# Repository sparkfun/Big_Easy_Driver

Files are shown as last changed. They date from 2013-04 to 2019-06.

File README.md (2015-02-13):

SparkFun Big Easy Driver
========================

SparkFun Big Easy Driver

[*SparkFun Big Easy Driver (ROB-12859)*](https://www.sparkfun.com/products/12859)

This is a stepper motor driver board capable of driving bi-polar stepper motors at up to 2A/phase.

Repository Contents
-------------------

* **/Firmware** - Example Arduino sketches 
* **/Hardware** - All Eagle design files (.brd, .sch)
* **/Production** - Test bed files and production panel files

Product Versions
----------------
* [ROB-12859](https://www.sparkfun.com/products/12859)- Version 1.6. Currently available. 
* [ROB-11876](https://www.sparkfun.com/products/retired/11876)- Version 1.5. Retired. 
* [ROB-11699](https://www.sparkfun.com/products/retired/11699)- Version 1.3. Retired. 
* [ROB-10735](https://www.sparkfun.com/products/retired/10735)- Version 1.2. Retired.

Version History
---------------
* [Hw-v1.6_Fw-v1.0](https://github.com/sparkfun/Big_Easy_Driver/tree/HW-v1.6_Fw-v1.0) -GitHub tag for hardware version 1.6, firmware version 1.0.  
* [HW-v1.5](https://github.com/sparkfun/Big_Easy_Driver/tree/HW-v1.5) - GitHub tag for Hardware version 1.5. 

License Information
-------------------
The hardware is released under [Creative Commons Share-alike 3.0](http://creativecommons.org/licenses/by-sa/3.0/).  

The code is beerware; if you see me (or any other SparkFun employee) at the local, and you've found our code helpful, please buy us a round!

Distributed as-is; no warranty is given.

Getting Started Help
--------------------
There's a great [Big Easy Driver Hookup Guide](https://learn.sparkfun.com/tutorials/big-easy-driver-hookup-guide) by SparkFun.

There are six example sketches in the **/Firmware** directory. Examples 1 through 5 have hookup diagrams and explanations on the [Easy Driver Examples](http://www.schmalzhaus.com/EasyDriver/Examples/EasyDriverExamples.html) page.

_This is a collaboration with Brian Schmalz._

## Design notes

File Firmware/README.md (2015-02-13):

SparkFun Big Easy Driver Example Code
======================================

Repository Contents
-------------------
* **/Arduija_Demo** - Firmware for the [Arduija Project](https://www.sparkfun.com/news/1631). 
* **/SparkFun_Big_Easy_Driver_Basic_Demo** - Firmware for the [Big Easy Driver Hookup Guide](https://learn.sparkfun.com/tutorials/big-easy-driver-hookup-guide).

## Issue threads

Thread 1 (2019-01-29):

Error on Code?

caroline-kornbrek, 2019-01-29:
I have been having trouble with the phrase  'resetBEDPins' . Whenever I try to verify my code, I get the message 'resetBEDPins' referring to the occurrence of this phrase in the void setup and void loop functions. As a result, I have been unable to get the code uploaded.

caroline-kornbrek, 2019-01-29:
I think we may be having the same conversation on github as well. I posted the question twice because I was not expecting a response so quickly. Where would you like to discuss? Thank you so much for your help.

Thanks,
Caroline Kornbrek

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

EmbeddedMan, 2019-01-29:
Caroline - when you post to GitHub, it comes through email as well. You can reply to either - they all show up on GH.

When I copy/pasted the code you provided into Arduino 1.8.7 and built for Arduino uno, I didn't get any errors or warnings.

Can you copy/paste the output of your compile (make sure to turn on verbose output for compilation in the preferences dialog box for Arduino first)? Maybe there's a clue there.

caroline-kornbrek, 2019-01-29:
Checking that box in the preferences allowed it to verify. Thank you!

EmbeddedMan, 2019-01-29:
Very good. I'm going to close this issue since the original issue appears to be solved. Please let us know if you have any other problems with the Big Easy Driver board.

Closed 2019-01-29.

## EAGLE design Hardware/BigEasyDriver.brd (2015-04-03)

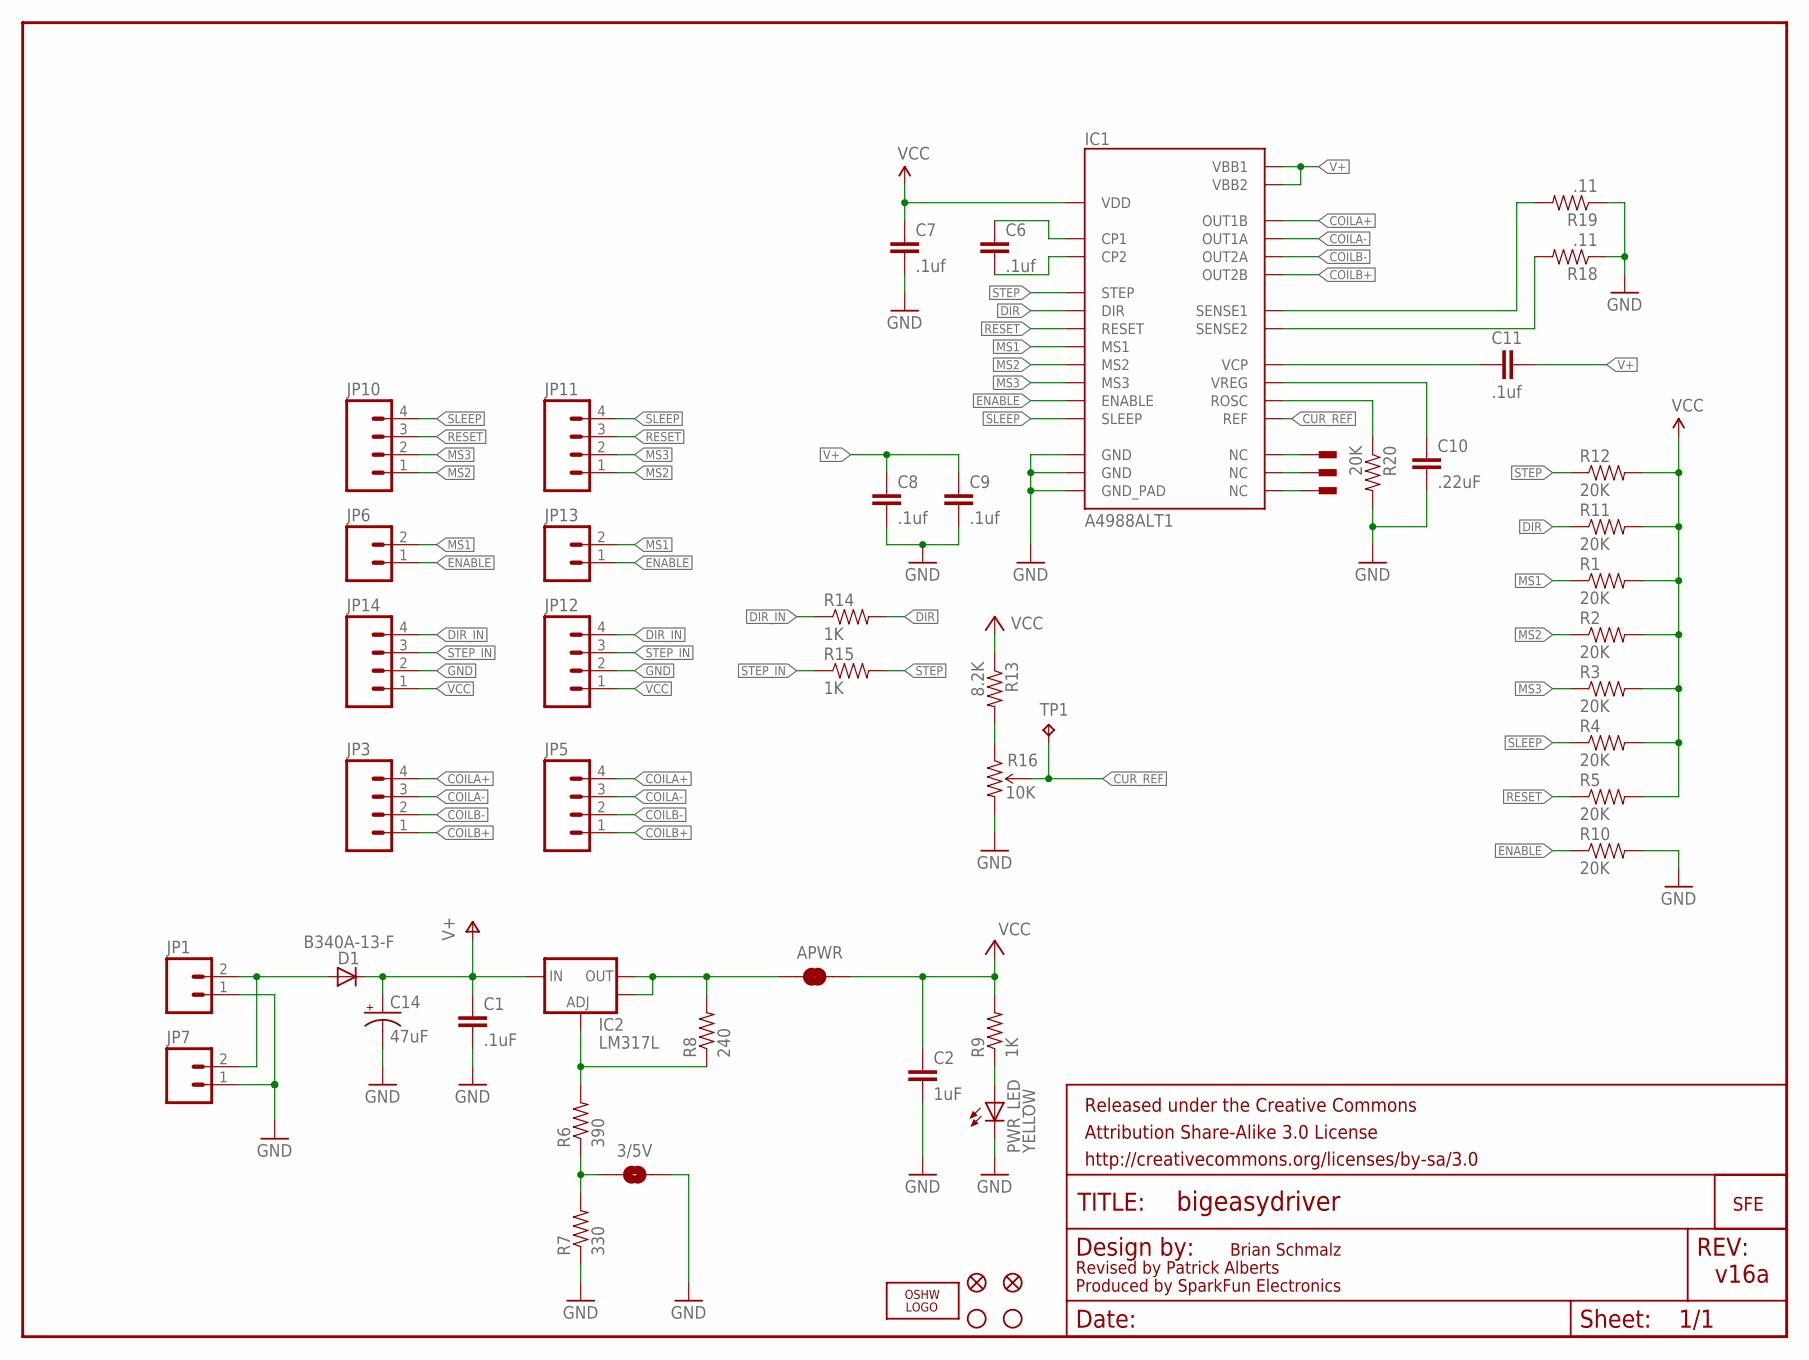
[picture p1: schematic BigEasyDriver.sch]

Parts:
3/5V: SOLDERJUMPERNO; SJ_2S-NO
APWR: SOLDERJUMPERTRACE; SJ_2S-TRACE
C1: .1uF; 0603-CAP
C2: 1uF; 0603-CAP
C6, C7, C8, C9, C11: .1uf; 0603-CAP
C10: .22uF; 0603-CAP
C14: 47uF; PANASONIC_D
D1: B340A-13-F; DO-214AC
FID1, FID2: FIDUCIAL1X2; FIDUCIAL-1X2
FRAME1: FRAME-LETTER; CREATIVE_COMMONS
IC1: A4988ALT1; QFN-28-5MM_ALT1
IC2: LM317L; SCHMALZHAUS_SOT89
JP1, JP6: M02PTH; 1X02
JP3, JP10, JP14: M04PTH; 1X04
JP5, JP11, JP12: M04SCREW_LOCK; SCREWTERMINAL-3.5MM-4_LOCK
JP7, JP13: M023.5MM_LOCK; SCREWTERMINAL-3.5MM-2_LOCK
JP8, JP9: STAND-OFF
LOGO1: OSHW_LOGO_FILLX0100-NT; OSHW_FILLX100_NOTEXT
PWR_LED: YELLOW; LED-0603
R1, R2, R3, R4, R5, R10, R11, R12, R20: 20K; 0603-RES
R6: 390; 0603-RES
R7: 330; 0603-RES
R8: 240; 0603-RES
R9, R14, R15: 1K; 0603-RES
R13: 8.2K; 0603-RES
R16: 10K; TRIMPOT-3MM-2
R18, R19: .11; R2010
TP1: TPPAD1-13; P1-13
U$2: LOGO-SFENEW; SFE-NEW-WEBLOGO
U$3, U$4, U$5: PAD; PAD-0.008

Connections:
5V_ALT: APWR.1, IC2.OUT, IC2.OUT@1 (OUT), R8.2
COILA+: IC1.P$21 (OUT1B), JP3.4, JP5.4
COILA-: IC1.P$24 (OUT1A), JP3.3, JP5.3
COILB+: IC1.P$1 (OUT2B), JP3.1, JP5.1
COILB-: IC1.P$26 (OUT2A), JP3.2, JP5.2
CUR_REF: IC1.P$17 (REF), R16.2 (WIPER), TP1.TP
DIR: IC1.P$19 (DIR), R11.1, R14.2
DIR_IN: JP12.4, JP14.4, R14.1
ENABLE: IC1.P$2 (ENABLE), JP6.1, JP13.1, R10.1
GND: 3/5V.2, C1.2, C2.2, C7.2, C8.2, C9.2, C10.2, C14.-, IC1.P$3 (GND), IC1.P$18 (GND), IC1.P$29 (GND_PAD), JP1.1, JP7.1, JP12.2, JP14.2, PWR_LED.C, R7.1, R10.2, R16.3 (CW), R18.1, R19.1, R20.2
MS1: IC1.P$9 (MS1), JP6.2, JP13.2, R1.1
MS2: IC1.P$10 (MS2), JP10.1, JP11.1, R2.1
MS3: IC1.P$11 (MS3), JP10.2, JP11.2, R3.1
unnamed: D1.A, JP1.2, JP7.2
unnamed: PWR_LED.A, R9.1
unnamed: R13.2, R16.1 (CCW)
unnamed: 3/5V.1, R6.1, R7.2
unnamed: IC1.P$7 (NC), U$3.P$1
unnamed: IC2.ADJ, R6.2, R8.1
unnamed: IC1.P$20 (NC), U$4.P$1
unnamed: C6.1, IC1.P$4 (CP1)
unnamed: C6.2, IC1.P$5 (CP2)
unnamed: IC1.P$25 (NC), U$5.P$1
unnamed: IC1.P$13 (ROSC), R20.1
unnamed: C10.1, IC1.P$8 (VREG)
unnamed: C11.1, IC1.P$6 (VCP)
unnamed: IC1.P$27 (SENSE2), R18.2
unnamed: IC1.P$23 (SENSE1), R19.2
RESET: IC1.P$12 (RESET), JP10.3, JP11.3, R5.1
SLEEP: IC1.P$14 (SLEEP), JP10.4, JP11.4, R4.1
STEP: IC1.P$16 (STEP), R12.1, R15.2
STEP_IN: JP12.3, JP14.3, R15.1
V+: C1.1, C8.1, C9.1, C11.2, C14.+, D1.C, IC1.P$22 (VBB1), IC1.P$28 (VBB2), IC2.IN
VCC: APWR.2, C2.1, C7.1, IC1.P$15 (VDD), JP12.1, JP14.1, R1.2, R2.2, R3.2, R4.2, R5.2, R9.2, R11.2, R12.2, R13.1

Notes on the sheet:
Brian Schmalz
Produced by SparkFun Electronics
v16a
Revised by Patrick Alberts

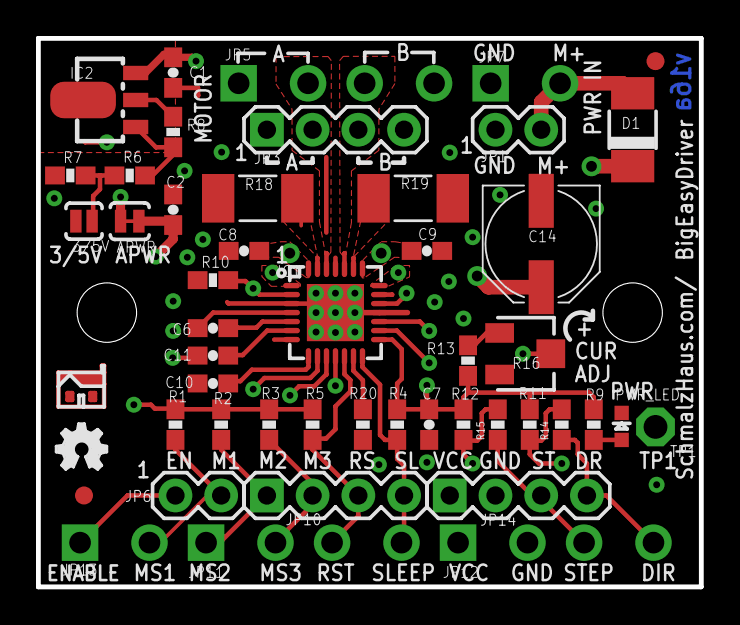
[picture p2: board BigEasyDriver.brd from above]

Board: 4 copper layers, 36.8 x 30.5 mm, 56 parts (1 on the bottom side), 34 nets.

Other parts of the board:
U$1: SCHMALZHAUS_SMALL

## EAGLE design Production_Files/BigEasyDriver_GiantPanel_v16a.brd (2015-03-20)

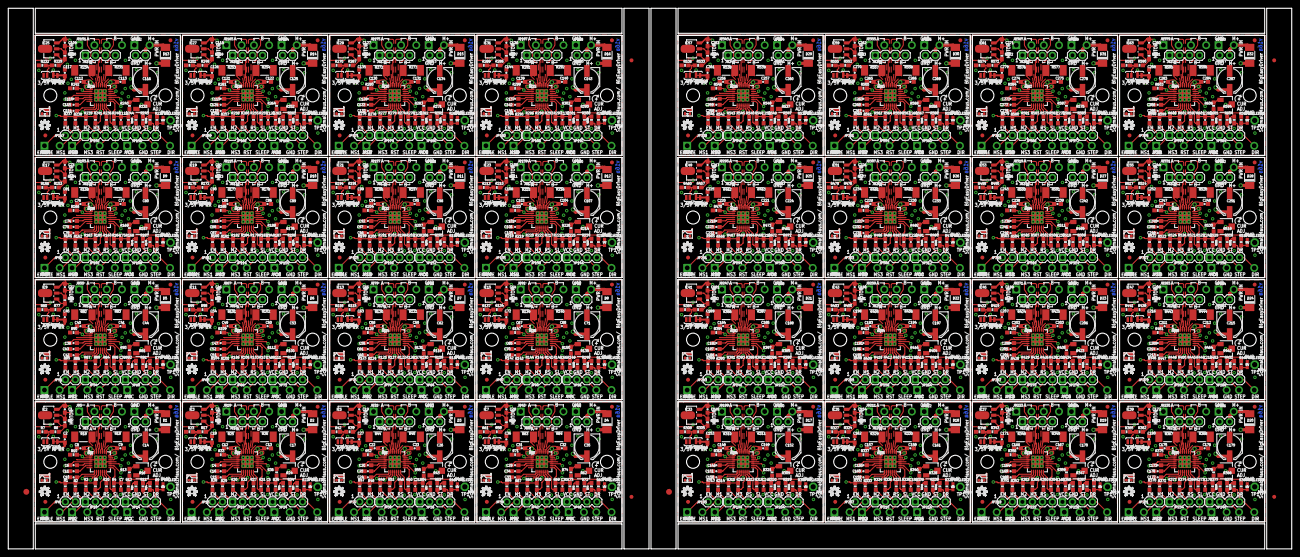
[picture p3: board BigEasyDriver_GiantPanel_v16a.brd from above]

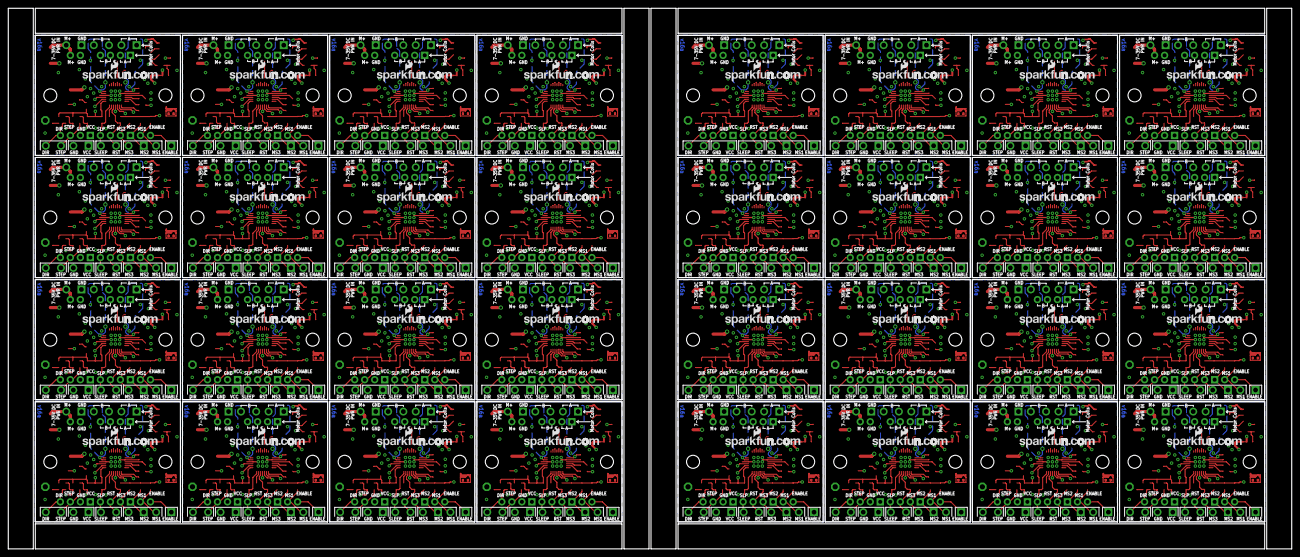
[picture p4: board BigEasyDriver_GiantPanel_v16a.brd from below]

Board: 4 copper layers, 325.6 x 137.2 mm, 1766 parts (32 on the bottom side), 1088 nets.

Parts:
3/5V, 3/5V1, 3/5V2, 3/5V3, 3/5V4, 3/5V5, 3/5V6, 3/5V7, 3/5V8, 3/5V9, 3/5V10, 3/5V11, 3/5V12, 3/5V13, 3/5V14, 3/5V15, 3/5V16, 3/5V17, 3/5V18, 3/5V19, 3/5V20, 3/5V21, 3/5V22, 3/5V23, 3/5V24, 3/5V25, 3/5V26, 3/5V27, 3/5V28, 3/5V29, 3/5V30, 3/5V31: SOLDERJUMPERNO; SJ_2S-NO
APWR, APWR1, APWR2, APWR3, APWR4, APWR5, APWR6, APWR7, APWR8, APWR9, APWR10, APWR11, APWR12, APWR13, APWR14, APWR15, APWR16, APWR17, APWR18, APWR19, APWR20, APWR21, APWR22, APWR23, APWR24, APWR25, APWR26, APWR27, APWR28, APWR29, APWR30, APWR31: SOLDERJUMPERTRACE; SJ_2S-TRACE
C1, C3, C19, C28, C37, C46, C55, C64, C73, C82, C91, C100, C109, C118, C127, C136, C145, C154, C163, C172, C181, C190, C199, C208, C217, C226, C235, C244, C253, C262, C271, C280: .1uF; 0603-CAP
C2, C18, C27, C36, C45, C54, C63, C72, C81, C90, C99, C108, C117, C126, C135, C144, C153, C162, C171, C180, C189, C198, C207, C216, C225, C234, C243, C252, C261, C270, C279, C288: 1uF; 0603-CAP
C4, C5, C6, C7, C8, C9, C11, C12, C13, C16, C20, C21, C22, C23, C25, C29, C30, C31, C32, C34, C38, C39, C40, C41, C43, C47, C48, C49, C50, C52, C56, C57, C58, C59, C61, C65, C66, C67, C68, C70, C74, C75, C76, C77, C79, C83, C84, C85, C86, C88, C92, C93, C94, C95, C97, C101, C102, C103, C104, C106, C110, C111, C112, C113, C115, C119, C120, C121, C122, C124, C128, C129, C130, C131, C133, C137, C138, C139, C140, C142, C146, C147, C148, C149, C151, C155, C156, C157, C158, C160, C164, C165, C166, C167, C169, C173, C174, C175, C176, C178, C182, C183, C184, C185, C187, C191, C192, C193, C194, C196, C200, C201, C202, C203, C205, C209, C210, C211, C212, C214, C218, C219, C220, C221, C223, C227, C228, C229, C230, C232, C236, C237, C238, C239, C241, C245, C246, C247, C248, C250, C254, C255, C256, C257, C259, C263, C264, C265, C266, C268, C272, C273, C274, C275, C277, C281, C282, C283, C284, C286: .1uf; 0603-CAP
C10, C15, C24, C33, C42, C51, C60, C69, C78, C87, C96, C105, C114, C123, C132, C141, C150, C159, C168, C177, C186, C195, C204, C213, C222, C231, C240, C249, C258, C267, C276, C285: .22uF; 0603-CAP
C14, C17, C26, C35, C44, C53, C62, C71, C80, C89, C98, C107, C116, C125, C134, C143, C152, C161, C170, C179, C188, C197, C206, C215, C224, C233, C242, C251, C260, C269, C278, C287: 47uF; PANASONIC_D
D1, D2, D3, D4, D5, D6, D7, D8, D9, D10, D11, D12, D13, D14, D15, D16, D17, D18, D19, D20, D21, D22, D23, D24, D25, D26, D27, D28, D29, D30, D31, D32: B340A-13-F; DO-214AC
E$1, E$4: FIDUCIAL-1.5X3
E$2, E$3, E$6, E$7: FIDUCIAL-1X2
FID1, FID2, FID3, FID4, FID5, FID6, FID7, FID8, FID9, FID10, FID11, FID12, FID13, FID14, FID15, FID16, FID17, FID18, FID19, FID20, FID21, FID22, FID23, FID24, FID25, FID26, FID27, FID28, FID29, FID30, FID31, FID32, FID33, FID34, FID35, FID36, FID37, FID38, FID39, FID40, FID41, FID42, FID43, FID44, FID45, FID46, FID47, FID48, FID49, FID50, FID51, FID52, FID53, FID54, FID55, FID56, FID57, FID58, FID59, FID60, FID61, FID62, FID63, FID64: FIDUCIAL1X2; FIDUCIAL-1X2
IC1, IC4, IC6, IC8, IC10, IC12, IC14, IC16, IC18, IC20, IC22, IC24, IC26, IC28, IC30, IC32, IC34, IC36, IC38, IC40, IC42, IC44, IC46, IC48, IC50, IC52, IC54, IC56, IC58, IC60, IC62, IC64: A4983ALT1; QFN-28-5MM_ALT1
IC2, IC3, IC5, IC7, IC9, IC11, IC13, IC15, IC17, IC19, IC21, IC23, IC25, IC27, IC29, IC31, IC33, IC35, IC37, IC39, IC41, IC43, IC45, IC47, IC49, IC51, IC53, IC55, IC57, IC59, IC61, IC63: LM317L; SCHMALZHAUS_SOT89
JP1, JP6, JP15, JP17, JP27, JP29, JP39, JP41, JP51, JP53, JP63, JP65, JP75, JP77, JP87, JP89, JP99, JP101, JP111, JP113, JP123, JP125, JP135, JP137, JP147, JP149, JP159, JP161, JP171, JP173, JP183, JP185, JP195, JP197, JP207, JP209, JP219, JP221, JP231, JP233, JP243, JP245, JP255, JP257, JP267, JP269, JP279, JP281, JP291, JP293, JP303, JP305, JP315, JP317, JP327, JP329, JP339, JP341, JP351, JP353, JP363, JP365, JP375, JP377: 1X02
JP2, JP4, JP8, JP9, JP25, JP26, JP37, JP38, JP49, JP50, JP61, JP62, JP73, JP74, JP85, JP86, JP97, JP98, JP109, JP110, JP121, JP122, JP133, JP134, JP145, JP146, JP157, JP158, JP169, JP170, JP181, JP182, JP193, JP194, JP205, JP206, JP217, JP218, JP229, JP230, JP241, JP242, JP253, JP254, JP265, JP266, JP277, JP278, JP289, JP290, JP301, JP302, JP313, JP314, JP325, JP326, JP337, JP338, JP349, JP350, JP361, JP362, JP373, JP374: STAND-OFF
JP3, JP10, JP14, JP16, JP18, JP24, JP28, JP30, JP36, JP40, JP42, JP48, JP52, JP54, JP60, JP64, JP66, JP72, JP76, JP78, JP84, JP88, JP90, JP96, JP100, JP102, JP108, JP112, JP114, JP120, JP124, JP126, JP132, JP136, JP138, JP144, JP148, JP150, JP156, JP160, JP162, JP168, JP172, JP174, JP180, JP184, JP186, JP192, JP196, JP198, JP204, JP208, JP210, JP216, JP220, JP222, JP228, JP232, JP234, JP240, JP244, JP246, JP252, JP256, JP258, JP264, JP268, JP270, JP276, JP280, JP282, JP288, JP292, JP294, JP300, JP304, JP306, JP312, JP316, JP318, JP324, JP328, JP330, JP336, JP340, JP342, JP348, JP352, JP354, JP360, JP364, JP366, JP372, JP376, JP378, JP384: 1X04
JP5, JP11, JP12, JP19, JP21, JP22, JP31, JP33, JP34, JP43, JP45, JP46, JP55, JP57, JP58, JP67, JP69, JP70, JP79, JP81, JP82, JP91, JP93, JP94, JP103, JP105, JP106, JP115, JP117, JP118, JP127, JP129, JP130, JP139, JP141, JP142, JP151, JP153, JP154, JP163, JP165, JP166, JP175, JP177, JP178, JP187, JP189, JP190, JP199, JP201, JP202, JP211, JP213, JP214, JP223, JP225, JP226, JP235, JP237, JP238, JP247, JP249, JP250, JP259, JP261, JP262, JP271, JP273, JP274, JP283, JP285, JP286, JP295, JP297, JP298, JP307, JP309, JP310, JP319, JP321, JP322, JP331, JP333, JP334, JP343, JP345, JP346, JP355, JP357, JP358, JP367, JP369, JP370, JP379, JP381, JP382: SCREWTERMINAL-3.5MM-4_LOCK
JP7, JP13, JP20, JP23, JP32, JP35, JP44, JP47, JP56, JP59, JP68, JP71, JP80, JP83, JP92, JP95, JP104, JP107, JP116, JP119, JP128, JP131, JP140, JP143, JP152, JP155, JP164, JP167, JP176, JP179, JP188, JP191, JP200, JP203, JP212, JP215, JP224, JP227, JP236, JP239, JP248, JP251, JP260, JP263, JP272, JP275, JP284, JP287, JP296, JP299, JP308, JP311, JP320, JP323, JP332, JP335, JP344, JP347, JP356, JP359, JP368, JP371, JP380, JP383: SCREWTERMINAL-3.5MM-2_LOCK
LOGO1, LOGO2, LOGO3, LOGO4, LOGO5, LOGO6, LOGO7, LOGO8, LOGO9, LOGO10, LOGO11, LOGO12, LOGO13, LOGO14, LOGO15, LOGO16, LOGO17, LOGO18, LOGO19, LOGO20, LOGO21, LOGO22, LOGO23, LOGO24, LOGO25, LOGO26, LOGO27, LOGO28, LOGO29, LOGO30, LOGO31, LOGO32: OSHW_LOGO_FILLX0100-NT; OSHW_FILLX100_NOTEXT
PWR_LED, PWR_LED1, PWR_LED2, PWR_LED3, PWR_LED4, PWR_LED5, PWR_LED6, PWR_LED7, PWR_LED8, PWR_LED9, PWR_LED10, PWR_LED11, PWR_LED12, PWR_LED13, PWR_LED14, PWR_LED15, PWR_LED16, PWR_LED17, PWR_LED18, PWR_LED19, PWR_LED20, PWR_LED21, PWR_LED22, PWR_LED23, PWR_LED24, PWR_LED25, PWR_LED26, PWR_LED27, PWR_LED28, PWR_LED29, PWR_LED30, PWR_LED31: YELLOW; LED-0603
R1, R2, R3, R4, R5, R10, R11, R12, R20, R27, R28, R29, R30, R31, R32, R33, R34, R35, R46, R47, R48, R49, R50, R51, R52, R53, R54, R65, R66, R67, R68, R69, R70, R71, R72, R73, R84, R85, R86, R87, R88, R89, R90, R91, R92, R103, R104, R105, R106, R107, R108, R109, R110, R111, R122, R123, R124, R125, R126, R127, R128, R129, R130, R141, R142, R143, R144, R145, R146, R147, R148, R149, R160, R161, R162, R163, R164, R165, R166, R167, R168, R179, R180, R181, R182, R183, R184, R185, R186, R187, R198, R199, R200, R201, R202, R203, R204, R205, R206, R217, R218, R219, R220, R221, R222, R223, R224, R225, R236, R237, R238, R239, R240, R241, R242, R243, R244, R255, R256, R257, R258, R259, R260, R261, R262, R263, R274, R275, R276, R277, R278, R279, R280, R281, R282, R293, R294, R295, R296, R297, R298, R299, R300, R301, R312, R313, R314, R315, R316, R317, R318, R319, R320, R331, R332, R333, R334, R335, R336, R337, R338, R339, R350, R351, R352, R353, R354, R355, R356, R357, R358, R369, R370, R371, R372, R373, R374, R375, R376, R377, R388, R389, R390, R391, R392, R393, R394, R395, R396, R407, R408, R409, R410, R411, R412, R413, R414, R415, R426, R427, R428, R429, R430, R431, R432, R433, R434, R445, R446, R447, R448, R449, R450, R451, R452, R453, R464, R465, R466, R467, R468, R469, R470, R471, R472, R483, R484, R485, R486, R487, R488, R489, R490, R491, R502, R503, R504, R505, R506, R507, R508, R509, R510, R521, R522, R523, R524, R525, R526, R527, R528, R529, R540, R541, R542, R543, R544, R545, R546, R547, R548, R559, R560, R561, R562, R563, R564, R565, R566, R567, R578, R579, R580, R581, R582, R583, R584, R585, R586, R597, R598, R599, R600, R601, R602, R603, R604, R605: 20K; 0603-RES
R6, R17, R39, R58, R77, R96, R115, R134, R153, R172, R191, R210, R229, R248, R267, R286, R305, R324, R343, R362, R381, R400, R419, R438, R457, R476, R495, R514, R533, R552, R571, R590: 390; 0603-RES
R7, R23, R42, R61, R80, R99, R118, R137, R156, R175, R194, R213, R232, R251, R270, R289, R308, R327, R346, R365, R384, R403, R422, R441, R460, R479, R498, R517, R536, R555, R574, R593: 330; 0603-RES
R8, R21, R40, R59, R78, R97, R116, R135, R154, R173, R192, R211, R230, R249, R268, R287, R306, R325, R344, R363, R382, R401, R420, R439, R458, R477, R496, R515, R534, R553, R572, R591: 240; 0603-RES
R9, R14, R15, R22, R37, R38, R41, R56, R57, R60, R75, R76, R79, R94, R95, R98, R113, R114, R117, R132, R133, R136, R151, R152, R155, R170, R171, R174, R189, R190, R193, R208, R209, R212, R227, R228, R231, R246, R247, R250, R265, R266, R269, R284, R285, R288, R303, R304, R307, R322, R323, R326, R341, R342, R345, R360, R361, R364, R379, R380, R383, R398, R399, R402, R417, R418, R421, R436, R437, R440, R455, R456, R459, R474, R475, R478, R493, R494, R497, R512, R513, R516, R531, R532, R535, R550, R551, R554, R569, R570, R573, R588, R589, R592, R607, R608: 1K; 0603-RES
R13, R36, R55, R74, R93, R112, R131, R150, R169, R188, R207, R226, R245, R264, R283, R302, R321, R340, R359, R378, R397, R416, R435, R454, R473, R492, R511, R530, R549, R568, R587, R606: 8.2K; 0603-RES
R16, R24, R43, R62, R81, R100, R119, R138, R157, R176, R195, R214, R233, R252, R271, R290, R309, R328, R347, R366, R385, R404, R423, R442, R461, R480, R499, R518, R537, R556, R575, R594: 10K; TRIMPOT-3MM-2
R18, R19, R25, R26, R44, R45, R63, R64, R82, R83, R101, R102, R120, R121, R139, R140, R158, R159, R177, R178, R196, R197, R215, R216, R234, R235, R253, R254, R272, R273, R291, R292, R310, R311, R329, R330, R348, R349, R367, R368, R386, R387, R405, R406, R424, R425, R443, R444, R462, R463, R481, R482, R500, R501, R519, R520, R538, R539, R557, R558, R576, R577, R595, R596: .11; R2010
TP1, TP2, TP3, TP4, TP5, TP6, TP7, TP8, TP9, TP10, TP11, TP12, TP13, TP14, TP15, TP16, TP17, TP18, TP19, TP20, TP21, TP22, TP23, TP24, TP25, TP26, TP27, TP28, TP29, TP30, TP31, TP32: TPPAD1-13; P1-13
U$1, U$6, U$11, U$16, U$21, U$26, U$31, U$36, U$41, U$46, U$51, U$56, U$61, U$66, U$71, U$76, U$81, U$86, U$91, U$96, U$101, U$106, U$111, U$116, U$121, U$126, U$131, U$136, U$141, U$146, U$151, U$156: SCHMALZHAUS_SMALL
U$2, U$7, U$12, U$17, U$22, U$27, U$32, U$37, U$42, U$47, U$52, U$57, U$62, U$67, U$72, U$77, U$82, U$87, U$92, U$97, U$102, U$107, U$112, U$117, U$122, U$127, U$132, U$137, U$142, U$147, U$152, U$157: LOGO-SFENEW; SFE-NEW-WEBLOGO
U$3, U$4, U$5, U$8, U$9, U$10, U$13, U$14, U$15, U$18, U$19, U$20, U$23, U$24, U$25, U$28, U$29, U$30, U$33, U$34, U$35, U$38, U$39, U$40, U$43, U$44, U$45, U$48, U$49, U$50, U$53, U$54, U$55, U$58, U$59, U$60, U$63, U$64, U$65, U$68, U$69, U$70, U$73, U$74, U$75, U$78, U$79, U$80, U$83, U$84, U$85, U$88, U$89, U$90, U$93, U$94, U$95, U$98, U$99, U$100, U$103, U$104, U$105, U$108, U$109, U$110, U$113, U$114, U$115, U$118, U$119, U$120, U$123, U$124, U$125, U$128, U$129, U$130, U$133, U$134, U$135, U$138, U$139, U$140, U$143, U$144, U$145, U$148, U$149, U$150, U$153, U$154, U$155, U$158, U$159, U$160: PAD; PAD-0.008

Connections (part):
5V_ALT: APWR.1, IC2.OUT, IC2.OUT@1, R8.2
5V_ALT1: APWR1.1, IC3.OUT, IC3.OUT@1, R21.2
5V_ALT2: APWR2.1, IC5.OUT, IC5.OUT@1, R40.2
5V_ALT3: APWR3.1, IC7.OUT, IC7.OUT@1, R59.2
5V_ALT4: APWR4.1, IC9.OUT, IC9.OUT@1, R78.2
5V_ALT5: APWR5.1, IC11.OUT, IC11.OUT@1, R97.2
5V_ALT6: APWR6.1, IC13.OUT, IC13.OUT@1, R116.2
5V_ALT7: APWR7.1, IC15.OUT, IC15.OUT@1, R135.2
5V_ALT8: APWR8.1, IC17.OUT, IC17.OUT@1, R154.2
5V_ALT9: APWR9.1, IC19.OUT, IC19.OUT@1, R173.2
5V_ALT10: APWR10.1, IC21.OUT, IC21.OUT@1, R192.2
5V_ALT11: APWR11.1, IC23.OUT, IC23.OUT@1, R211.2
5V_ALT12: APWR12.1, IC25.OUT, IC25.OUT@1, R230.2
5V_ALT13: APWR13.1, IC27.OUT, IC27.OUT@1, R249.2
5V_ALT14: APWR14.1, IC29.OUT, IC29.OUT@1, R268.2
5V_ALT15: APWR15.1, IC31.OUT, IC31.OUT@1, R287.2
5V_ALT16: APWR16.1, IC33.OUT, IC33.OUT@1, R306.2
5V_ALT17: APWR17.1, IC35.OUT, IC35.OUT@1, R325.2
5V_ALT18: APWR18.1, IC37.OUT, IC37.OUT@1, R344.2
5V_ALT19: APWR19.1, IC39.OUT, IC39.OUT@1, R363.2
5V_ALT20: APWR20.1, IC41.OUT, IC41.OUT@1, R382.2
5V_ALT21: APWR21.1, IC43.OUT, IC43.OUT@1, R401.2
5V_ALT22: APWR22.1, IC45.OUT, IC45.OUT@1, R420.2
5V_ALT23: APWR23.1, IC47.OUT, IC47.OUT@1, R439.2
5V_ALT24: APWR24.1, IC49.OUT, IC49.OUT@1, R458.2
5V_ALT25: APWR25.1, IC51.OUT, IC51.OUT@1, R477.2
5V_ALT26: APWR26.1, IC53.OUT, IC53.OUT@1, R496.2
5V_ALT27: APWR27.1, IC55.OUT, IC55.OUT@1, R515.2
5V_ALT28: APWR28.1, IC57.OUT, IC57.OUT@1, R534.2
5V_ALT29: APWR29.1, IC59.OUT, IC59.OUT@1, R553.2
5V_ALT30: APWR30.1, IC61.OUT, IC61.OUT@1, R572.2
5V_ALT31: APWR31.1, IC63.OUT, IC63.OUT@1, R591.2
COILA+: IC1.P$21, JP3.4, JP5.4
COILA+1: IC4.P$21, JP16.4, JP19.4
COILA+2: IC6.P$21, JP28.4, JP31.4
COILA+3: IC8.P$21, JP40.4, JP43.4
COILA+4: IC10.P$21, JP52.4, JP55.4
COILA+5: IC12.P$21, JP64.4, JP67.4
COILA+6: IC14.P$21, JP76.4, JP79.4
COILA+7: IC16.P$21, JP88.4, JP91.4
COILA+8: IC18.P$21, JP100.4, JP103.4
COILA+9: IC20.P$21, JP112.4, JP115.4
COILA+10: IC22.P$21, JP124.4, JP127.4
COILA+11: IC24.P$21, JP136.4, JP139.4
COILA+12: IC26.P$21, JP148.4, JP151.4
COILA+13: IC28.P$21, JP160.4, JP163.4
COILA+14: IC30.P$21, JP172.4, JP175.4
COILA+15: IC32.P$21, JP184.4, JP187.4
COILA+16: IC34.P$21, JP196.4, JP199.4
COILA+17: IC36.P$21, JP208.4, JP211.4
COILA+18: IC38.P$21, JP220.4, JP223.4
COILA+19: IC40.P$21, JP232.4, JP235.4
COILA+20: IC42.P$21, JP244.4, JP247.4
COILA+21: IC44.P$21, JP256.4, JP259.4
COILA+22: IC46.P$21, JP268.4, JP271.4
COILA+23: IC48.P$21, JP280.4, JP283.4
COILA+24: IC50.P$21, JP292.4, JP295.4
COILA+25: IC52.P$21, JP304.4, JP307.4
COILA+26: IC54.P$21, JP316.4, JP319.4
COILA+27: IC56.P$21, JP328.4, JP331.4
COILA+28: IC58.P$21, JP340.4, JP343.4
COILA+29: IC60.P$21, JP352.4, JP355.4
COILA+30: IC62.P$21, JP364.4, JP367.4
COILA+31: IC64.P$21, JP376.4, JP379.4
COILA-: IC1.P$24, JP3.3, JP5.3
COILA-1: IC4.P$24, JP16.3, JP19.3
COILA-2: IC6.P$24, JP28.3, JP31.3
COILA-3: IC8.P$24, JP40.3, JP43.3
COILA-4: IC10.P$24, JP52.3, JP55.3
COILA-5: IC12.P$24, JP64.3, JP67.3
COILA-6: IC14.P$24, JP76.3, JP79.3
COILA-7: IC16.P$24, JP88.3, JP91.3
COILA-8: IC18.P$24, JP100.3, JP103.3
COILA-9: IC20.P$24, JP112.3, JP115.3
COILA-10: IC22.P$24, JP124.3, JP127.3
COILA-11: IC24.P$24, JP136.3, JP139.3
COILA-12: IC26.P$24, JP148.3, JP151.3
COILA-13: IC28.P$24, JP160.3, JP163.3
COILA-14: IC30.P$24, JP172.3, JP175.3
COILA-15: IC32.P$24, JP184.3, JP187.3
COILA-16: IC34.P$24, JP196.3, JP199.3
COILA-17: IC36.P$24, JP208.3, JP211.3
COILA-18: IC38.P$24, JP220.3, JP223.3
COILA-19: IC40.P$24, JP232.3, JP235.3
COILA-20: IC42.P$24, JP244.3, JP247.3
COILA-21: IC44.P$24, JP256.3, JP259.3
COILA-22: IC46.P$24, JP268.3, JP271.3
COILA-23: IC48.P$24, JP280.3, JP283.3
COILA-24: IC50.P$24, JP292.3, JP295.3
COILA-25: IC52.P$24, JP304.3, JP307.3
COILA-26: IC54.P$24, JP316.3, JP319.3
COILA-27: IC56.P$24, JP328.3, JP331.3
COILA-28: IC58.P$24, JP340.3, JP343.3
COILA-29: IC60.P$24, JP352.3, JP355.3
COILA-30: IC62.P$24, JP364.3, JP367.3
COILA-31: IC64.P$24, JP376.3, JP379.3
COILB+: IC1.P$1, JP3.1, JP5.1
COILB+1: IC4.P$1, JP16.1, JP19.1
COILB+2: IC6.P$1, JP28.1, JP31.1
COILB+3: IC8.P$1, JP40.1, JP43.1
COILB+4: IC10.P$1, JP52.1, JP55.1
COILB+5: IC12.P$1, JP64.1, JP67.1
COILB+6: IC14.P$1, JP76.1, JP79.1
COILB+7: IC16.P$1, JP88.1, JP91.1
COILB+8: IC18.P$1, JP100.1, JP103.1
COILB+9: IC20.P$1, JP112.1, JP115.1
COILB+10: IC22.P$1, JP124.1, JP127.1
COILB+11: IC24.P$1, JP136.1, JP139.1
COILB+12: IC26.P$1, JP148.1, JP151.1
COILB+13: IC28.P$1, JP160.1, JP163.1
COILB+14: IC30.P$1, JP172.1, JP175.1
COILB+15: IC32.P$1, JP184.1, JP187.1
COILB+16: IC34.P$1, JP196.1, JP199.1
COILB+17: IC36.P$1, JP208.1, JP211.1
COILB+18: IC38.P$1, JP220.1, JP223.1
COILB+19: IC40.P$1, JP232.1, JP235.1
COILB+20: IC42.P$1, JP244.1, JP247.1
COILB+21: IC44.P$1, JP256.1, JP259.1
COILB+22: IC46.P$1, JP268.1, JP271.1
COILB+23: IC48.P$1, JP280.1, JP283.1
COILB+24: IC50.P$1, JP292.1, JP295.1
COILB+25: IC52.P$1, JP304.1, JP307.1
COILB+26: IC54.P$1, JP316.1, JP319.1
COILB+27: IC56.P$1, JP328.1, JP331.1
COILB+28: IC58.P$1, JP340.1, JP343.1
COILB+29: IC60.P$1, JP352.1, JP355.1
COILB+30: IC62.P$1, JP364.1, JP367.1
COILB+31: IC64.P$1, JP376.1, JP379.1
COILB-: IC1.P$26, JP3.2, JP5.2
COILB-1: IC4.P$26, JP16.2, JP19.2
COILB-2: IC6.P$26, JP28.2, JP31.2
COILB-3: IC8.P$26, JP40.2, JP43.2
COILB-4: IC10.P$26, JP52.2, JP55.2
COILB-5: IC12.P$26, JP64.2, JP67.2
COILB-6: IC14.P$26, JP76.2, JP79.2
COILB-7: IC16.P$26, JP88.2, JP91.2
COILB-8: IC18.P$26, JP100.2, JP103.2
COILB-9: IC20.P$26, JP112.2, JP115.2
COILB-10: IC22.P$26, JP124.2, JP127.2
COILB-11: IC24.P$26, JP136.2, JP139.2
COILB-12: IC26.P$26, JP148.2, JP151.2
COILB-13: IC28.P$26, JP160.2, JP163.2
COILB-14: IC30.P$26, JP172.2, JP175.2
COILB-15: IC32.P$26, JP184.2, JP187.2
COILB-16: IC34.P$26, JP196.2, JP199.2
COILB-17: IC36.P$26, JP208.2, JP211.2
COILB-18: IC38.P$26, JP220.2, JP223.2
COILB-19: IC40.P$26, JP232.2, JP235.2
COILB-20: IC42.P$26, JP244.2, JP247.2
COILB-21: IC44.P$26, JP256.2, JP259.2
COILB-22: IC46.P$26, JP268.2, JP271.2
COILB-23: IC48.P$26, JP280.2, JP283.2
COILB-24: IC50.P$26, JP292.2, JP295.2
COILB-25: IC52.P$26, JP304.2, JP307.2
COILB-26: IC54.P$26, JP316.2, JP319.2
COILB-27: IC56.P$26, JP328.2, JP331.2
COILB-28: IC58.P$26, JP340.2, JP343.2
COILB-29: IC60.P$26, JP352.2, JP355.2
COILB-30: IC62.P$26, JP364.2, JP367.2
COILB-31: IC64.P$26, JP376.2, JP379.2
CUR_REF: IC1.P$17, R16.2, TP1.TP
CUR_REF1: IC4.P$17, R24.2, TP2.TP
CUR_REF2: IC6.P$17, R43.2, TP3.TP
CUR_REF3: IC8.P$17, R62.2, TP4.TP
CUR_REF4: IC10.P$17, R81.2, TP5.TP
CUR_REF5: IC12.P$17, R100.2, TP6.TP
CUR_REF6: IC14.P$17, R119.2, TP7.TP
CUR_REF7: IC16.P$17, R138.2, TP8.TP
CUR_REF8: IC18.P$17, R157.2, TP9.TP
CUR_REF9: IC20.P$17, R176.2, TP10.TP
CUR_REF10: IC22.P$17, R195.2, TP11.TP
CUR_REF11: IC24.P$17, R214.2, TP12.TP
CUR_REF12: IC26.P$17, R233.2, TP13.TP
CUR_REF13: IC28.P$17, R252.2, TP14.TP
CUR_REF14: IC30.P$17, R271.2, TP15.TP
CUR_REF15: IC32.P$17, R290.2, TP16.TP
CUR_REF16: IC34.P$17, R309.2, TP17.TP
CUR_REF17: IC36.P$17, R328.2, TP18.TP
CUR_REF18: IC38.P$17, R347.2, TP19.TP
CUR_REF19: IC40.P$17, R366.2, TP20.TP
CUR_REF20: IC42.P$17, R385.2, TP21.TP
CUR_REF21: IC44.P$17, R404.2, TP22.TP
CUR_REF22: IC46.P$17, R423.2, TP23.TP
CUR_REF23: IC48.P$17, R442.2, TP24.TP
CUR_REF24: IC50.P$17, R461.2, TP25.TP
CUR_REF25: IC52.P$17, R480.2, TP26.TP
CUR_REF26: IC54.P$17, R499.2, TP27.TP
CUR_REF27: IC56.P$17, R518.2, TP28.TP
CUR_REF28: IC58.P$17, R537.2, TP29.TP
CUR_REF29: IC60.P$17, R556.2, TP30.TP
CUR_REF30: IC62.P$17, R575.2, TP31.TP
CUR_REF31: IC64.P$17, R594.2, TP32.TP
DIR: IC1.P$19, R11.1, R14.2
DIR1: IC4.P$19, R34.1, R37.2
DIR2: IC6.P$19, R53.1, R56.2
DIR3: IC8.P$19, R72.1, R75.2
DIR4: IC10.P$19, R91.1, R94.2
DIR5: IC12.P$19, R110.1, R113.2
DIR6: IC14.P$19, R129.1, R132.2
DIR7: IC16.P$19, R148.1, R151.2
DIR8: IC18.P$19, R167.1, R170.2
DIR9: IC20.P$19, R186.1, R189.2
DIR10: IC22.P$19, R205.1, R208.2
DIR11: IC24.P$19, R224.1, R227.2
DIR12: IC26.P$19, R243.1, R246.2
DIR13: IC28.P$19, R262.1, R265.2
DIR14: IC30.P$19, R281.1, R284.2
DIR15: IC32.P$19, R300.1, R303.2
DIR16: IC34.P$19, R319.1, R322.2
DIR17: IC36.P$19, R338.1, R341.2
DIR18: IC38.P$19, R357.1, R360.2
DIR19: IC40.P$19, R376.1, R379.2
DIR20: IC42.P$19, R395.1, R398.2
DIR21: IC44.P$19, R414.1, R417.2
DIR22: IC46.P$19, R433.1, R436.2
DIR23: IC48.P$19, R452.1, R455.2
DIR24: IC50.P$19, R471.1, R474.2
DIR25: IC52.P$19, R490.1, R493.2
DIR26: IC54.P$19, R509.1, R512.2
DIR27: IC56.P$19, R528.1, R531.2
DIR28: IC58.P$19, R547.1, R550.2
DIR29: IC60.P$19, R566.1, R569.2
DIR30: IC62.P$19, R585.1, R588.2
DIR31: IC64.P$19, R604.1, R607.2
DIR_IN: JP12.4, JP14.4, R14.1
DIR_IN1: JP22.4, JP24.4, R37.1
DIR_IN2: JP34.4, JP36.4, R56.1
DIR_IN3: JP46.4, JP48.4, R75.1
DIR_IN4: JP58.4, JP60.4, R94.1
DIR_IN5: JP70.4, JP72.4, R113.1
DIR_IN6: JP82.4, JP84.4, R132.1
DIR_IN7: JP94.4, JP96.4, R151.1
DIR_IN8: JP106.4, JP108.4, R170.1
DIR_IN9: JP118.4, JP120.4, R189.1
DIR_IN10: JP130.4, JP132.4, R208.1
DIR_IN11: JP142.4, JP144.4, R227.1
DIR_IN12: JP154.4, JP156.4, R246.1
DIR_IN13: JP166.4, JP168.4, R265.1
DIR_IN14: JP178.4, JP180.4, R284.1
DIR_IN15: JP190.4, JP192.4, R303.1
DIR_IN16: JP202.4, JP204.4, R322.1
DIR_IN17: JP214.4, JP216.4, R341.1
DIR_IN18: JP226.4, JP228.4, R360.1
DIR_IN19: JP238.4, JP240.4, R379.1
DIR_IN20: JP250.4, JP252.4, R398.1
DIR_IN21: JP262.4, JP264.4, R417.1
DIR_IN22: JP274.4, JP276.4, R436.1
DIR_IN23: JP286.4, JP288.4, R455.1
DIR_IN24: JP298.4, JP300.4, R474.1
DIR_IN25: JP310.4, JP312.4, R493.1
DIR_IN26: JP322.4, JP324.4, R512.1
DIR_IN27: JP334.4, JP336.4, R531.1
DIR_IN28: JP346.4, JP348.4, R550.1
DIR_IN29: JP358.4, JP360.4, R569.1
DIR_IN30: JP370.4, JP372.4, R588.1
DIR_IN31: JP382.4, JP384.4, R607.1
ENABLE: IC1.P$2, JP6.1, JP13.1, R10.1
ENABLE1: IC4.P$2, JP15.1, JP23.1, R33.1
ENABLE2: IC6.P$2, JP27.1, JP35.1, R52.1
ENABLE3: IC8.P$2, JP39.1, JP47.1, R71.1
ENABLE4: IC10.P$2, JP51.1, JP59.1, R90.1
ENABLE5: IC12.P$2, JP63.1, JP71.1, R109.1
ENABLE6: IC14.P$2, JP75.1, JP83.1, R128.1
ENABLE7: IC16.P$2, JP87.1, JP95.1, R147.1
ENABLE8: IC18.P$2, JP99.1, JP107.1, R166.1
ENABLE9: IC20.P$2, JP111.1, JP119.1, R185.1
ENABLE10: IC22.P$2, JP123.1, JP131.1, R204.1
ENABLE11: IC24.P$2, JP135.1, JP143.1, R223.1
ENABLE12: IC26.P$2, JP147.1, JP155.1, R242.1
ENABLE13: IC28.P$2, JP159.1, JP167.1, R261.1
ENABLE14: IC30.P$2, JP171.1, JP179.1, R280.1
ENABLE15: IC32.P$2, JP183.1, JP191.1, R299.1
ENABLE16: IC34.P$2, JP195.1, JP203.1, R318.1
ENABLE17: IC36.P$2, JP207.1, JP215.1, R337.1
ENABLE18: IC38.P$2, JP219.1, JP227.1, R356.1
ENABLE19: IC40.P$2, JP231.1, JP239.1, R375.1
ENABLE20: IC42.P$2, JP243.1, JP251.1, R394.1
ENABLE21: IC44.P$2, JP255.1, JP263.1, R413.1
ENABLE22: IC46.P$2, JP267.1, JP275.1, R432.1
ENABLE23: IC48.P$2, JP279.1, JP287.1, R451.1
ENABLE24: IC50.P$2, JP291.1, JP299.1, R470.1
ENABLE25: IC52.P$2, JP303.1, JP311.1, R489.1
ENABLE26: IC54.P$2, JP315.1, JP323.1, R508.1
ENABLE27: IC56.P$2, JP327.1, JP335.1, R527.1
ENABLE28: IC58.P$2, JP339.1, JP347.1, R546.1
ENABLE29: IC60.P$2, JP351.1, JP359.1, R565.1
ENABLE30: IC62.P$2, JP363.1, JP371.1, R584.1
ENABLE31: IC64.P$2, JP375.1, JP383.1, R603.1
GND: 3/5V.2, C1.2, C2.2, C7.2, C8.2, C9.2, C10.2, C14.-, IC1.P$3, IC1.P$18, IC1.P$29, JP1.1, JP7.1, JP12.2, JP14.2, PWR_LED.C, R7.1, R10.2, R16.3, R18.1, R19.1, R20.2
GND1: 3/5V1.2, C3.2, C5.2, C12.2, C13.2, C15.2, C17.-, C18.2, IC4.P$3, IC4.P$18, IC4.P$29, JP17.1, JP20.1, JP22.2, JP24.2, PWR_LED1.C, R23.1, R24.3, R25.1, R26.1, R27.2, R33.2
GND2: 3/5V2.2, C19.2, C21.2, C22.2, C23.2, C24.2, C26.-, C27.2, IC6.P$3, IC6.P$18, IC6.P$29, JP29.1, JP32.1, JP34.2, JP36.2, PWR_LED2.C, R42.1, R43.3, R44.1, R45.1, R46.2, R52.2
GND3: 3/5V3.2, C28.2, C30.2, C31.2, C32.2, C33.2, C35.-, C36.2, IC8.P$3, IC8.P$18, IC8.P$29, JP41.1, JP44.1, JP46.2, JP48.2, PWR_LED3.C, R61.1, R62.3, R63.1, R64.1, R65.2, R71.2
GND4: 3/5V4.2, C37.2, C39.2, C40.2, C41.2, C42.2, C44.-, C45.2, IC10.P$3, IC10.P$18, IC10.P$29, JP53.1, JP56.1, JP58.2, JP60.2, PWR_LED4.C, R80.1, R81.3, R82.1, R83.1, R84.2, R90.2
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

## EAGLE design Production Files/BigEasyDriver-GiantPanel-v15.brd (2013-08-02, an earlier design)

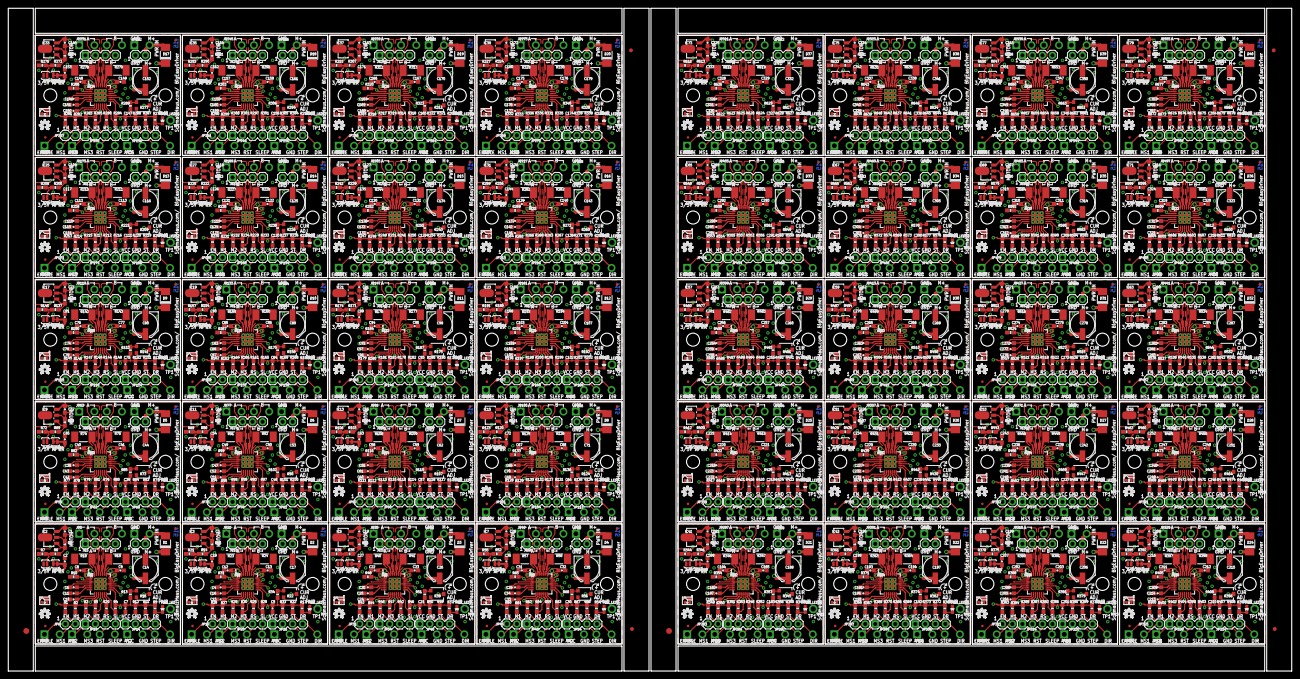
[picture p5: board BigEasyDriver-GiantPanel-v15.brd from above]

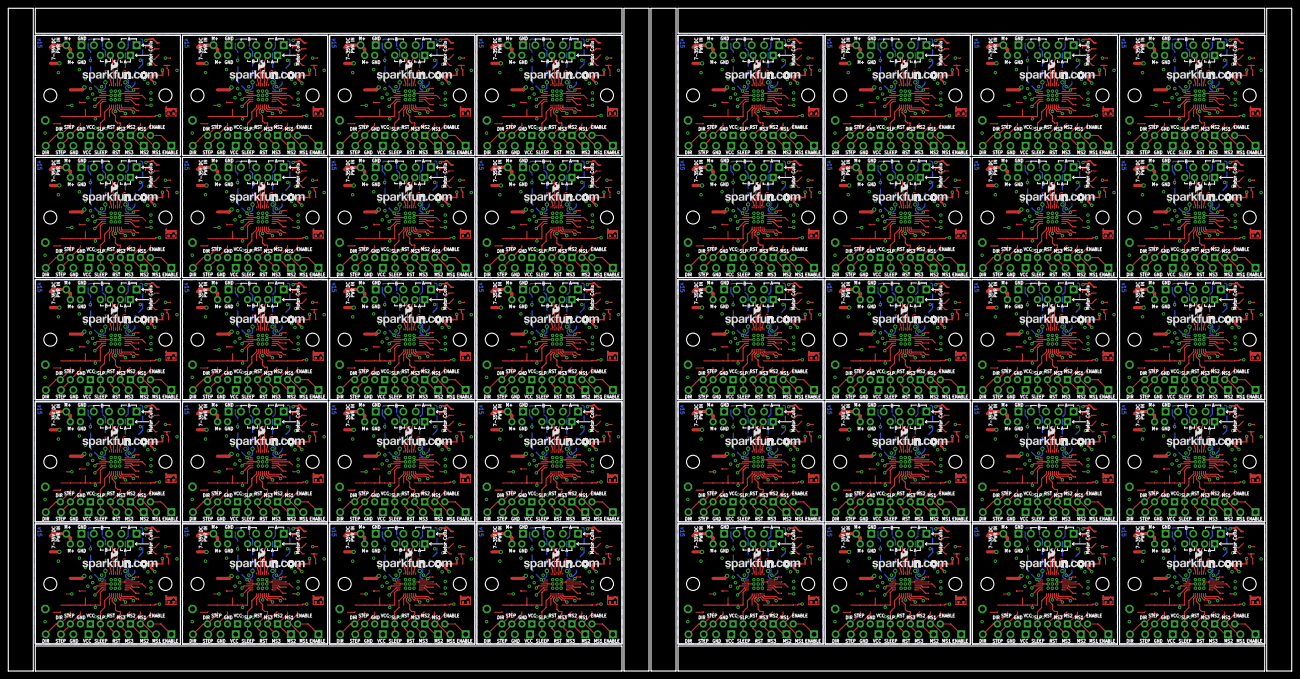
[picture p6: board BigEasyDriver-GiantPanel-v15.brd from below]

Board: 2 copper layers, 325.6 x 168.1 mm, 2126 parts (40 on the bottom side), 1280 nets.

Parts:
3/5V, 3/5V1, 3/5V2, 3/5V3, 3/5V4, 3/5V5, 3/5V6, 3/5V7, 3/5V8, 3/5V9, 3/5V10, 3/5V11, 3/5V12, 3/5V13, 3/5V14, 3/5V15, 3/5V16, 3/5V17, 3/5V18, 3/5V19, 3/5V20, 3/5V21, 3/5V22, 3/5V23, 3/5V24, 3/5V25, 3/5V26, 3/5V27, 3/5V28, 3/5V29, 3/5V30, 3/5V31, 3/5V32, 3/5V33, 3/5V34, 3/5V35, 3/5V36, 3/5V37, 3/5V38, 3/5V39: SOLDERJUMPERNO; SJ_2S-NO
APWR, APWR1, APWR2, APWR3, APWR4, APWR5, APWR6, APWR7, APWR8, APWR9, APWR10, APWR11, APWR12, APWR13, APWR14, APWR15, APWR16, APWR17, APWR18, APWR19, APWR20, APWR21, APWR22, APWR23, APWR24, APWR25, APWR26, APWR27, APWR28, APWR29, APWR30, APWR31, APWR32, APWR33, APWR34, APWR35, APWR36, APWR37, APWR38, APWR39: SOLDERJUMPERTRACE; SJ_2S-TRACE
C1, C3, C19, C28, C37, C46, C55, C64, C73, C82, C91, C100, C109, C118, C127, C136, C145, C154, C163, C172, C181, C190, C199, C208, C217, C226, C235, C244, C253, C262, C271, C280, C289, C298, C307, C316, C325, C334, C343, C352: .1uF; 0603-CAP
C2, C18, C27, C36, C45, C54, C63, C72, C81, C90, C99, C108, C117, C126, C135, C144, C153, C162, C171, C180, C189, C198, C207, C216, C225, C234, C243, C252, C261, C270, C279, C288, C297, C306, C315, C324, C333, C342, C351, C360: 1uF; 0603-CAP
C4, C5, C6, C7, C8, C9, C11, C12, C13, C16, C20, C21, C22, C23, C25, C29, C30, C31, C32, C34, C38, C39, C40, C41, C43, C47, C48, C49, C50, C52, C56, C57, C58, C59, C61, C65, C66, C67, C68, C70, C74, C75, C76, C77, C79, C83, C84, C85, C86, C88, C92, C93, C94, C95, C97, C101, C102, C103, C104, C106, C110, C111, C112, C113, C115, C119, C120, C121, C122, C124, C128, C129, C130, C131, C133, C137, C138, C139, C140, C142, C146, C147, C148, C149, C151, C155, C156, C157, C158, C160, C164, C165, C166, C167, C169, C173, C174, C175, C176, C178, C182, C183, C184, C185, C187, C191, C192, C193, C194, C196, C200, C201, C202, C203, C205, C209, C210, C211, C212, C214, C218, C219, C220, C221, C223, C227, C228, C229, C230, C232, C236, C237, C238, C239, C241, C245, C246, C247, C248, C250, C254, C255, C256, C257, C259, C263, C264, C265, C266, C268, C272, C273, C274, C275, C277, C281, C282, C283, C284, C286, C290, C291, C292, C293, C295, C299, C300, C301, C302, C304, C308, C309, C310, C311, C313, C317, C318, C319, C320, C322, C326, C327, C328, C329, C331, C335, C336, C337, C338, C340, C344, C345, C346, C347, C349, C353, C354, C355, C356, C358: .1uf; 0603-CAP
C10, C15, C24, C33, C42, C51, C60, C69, C78, C87, C96, C105, C114, C123, C132, C141, C150, C159, C168, C177, C186, C195, C204, C213, C222, C231, C240, C249, C258, C267, C276, C285, C294, C303, C312, C321, C330, C339, C348, C357: .22uF; 0603-CAP
C14, C17, C26, C35, C44, C53, C62, C71, C80, C89, C98, C107, C116, C125, C134, C143, C152, C161, C170, C179, C188, C197, C206, C215, C224, C233, C242, C251, C260, C269, C278, C287, C296, C305, C314, C323, C332, C341, C350, C359: 47uF; PANASONIC_D
D1, D2, D3, D4, D5, D6, D7, D8, D9, D10, D11, D12, D13, D14, D15, D16, D17, D18, D19, D20, D21, D22, D23, D24, D25, D26, D27, D28, D29, D30, D31, D32, D33, D34, D35, D36, D37, D38, D39, D40: B340A-13-F; DO-214AC
E$1, E$5: FIDUCIAL-1.5X3
E$2, E$3, E$4, E$6: FIDUCIAL-1X2
IC1, IC4, IC6, IC8, IC10, IC12, IC14, IC16, IC18, IC20, IC22, IC24, IC26, IC28, IC30, IC32, IC34, IC36, IC38, IC40, IC42, IC44, IC46, IC48, IC50, IC52, IC54, IC56, IC58, IC60, IC62, IC64, IC66, IC68, IC70, IC72, IC74, IC76, IC78, IC80: A4983ALT1; QFN-28-5MM_ALT1
IC2, IC3, IC5, IC7, IC9, IC11, IC13, IC15, IC17, IC19, IC21, IC23, IC25, IC27, IC29, IC31, IC33, IC35, IC37, IC39, IC41, IC43, IC45, IC47, IC49, IC51, IC53, IC55, IC57, IC59, IC61, IC63, IC65, IC67, IC69, IC71, IC73, IC75, IC77, IC79: LM317L; SCHMALZHAUS_SOT89
JP1, JP6, JP17, JP19, JP31, JP33, JP45, JP47, JP59, JP61, JP73, JP75, JP87, JP89, JP101, JP103, JP115, JP117, JP129, JP131, JP143, JP145, JP157, JP159, JP171, JP173, JP185, JP187, JP199, JP201, JP213, JP215, JP227, JP229, JP241, JP243, JP255, JP257, JP269, JP271, JP283, JP285, JP297, JP299, JP311, JP313, JP325, JP327, JP339, JP341, JP353, JP355, JP367, JP369, JP381, JP383, JP395, JP397, JP409, JP411, JP423, JP425, JP437, JP439, JP451, JP453, JP465, JP467, JP479, JP481, JP493, JP495, JP507, JP509, JP521, JP523, JP535, JP537, JP549, JP551: 1X02
JP2, JP4, JP27, JP28, JP41, JP42, JP55, JP56, JP69, JP70, JP83, JP84, JP97, JP98, JP111, JP112, JP125, JP126, JP139, JP140, JP153, JP154, JP167, JP168, JP181, JP182, JP195, JP196, JP209, JP210, JP223, JP224, JP237, JP238, JP251, JP252, JP265, JP266, JP279, JP280, JP293, JP294, JP307, JP308, JP321, JP322, JP335, JP336, JP349, JP350, JP363, JP364, JP377, JP378, JP391, JP392, JP405, JP406, JP419, JP420, JP433, JP434, JP447, JP448, JP461, JP462, JP475, JP476, JP489, JP490, JP503, JP504, JP517, JP518, JP531, JP532, JP545, JP546, JP559, JP560: FIDUCIAL1X2.5; FIDUCIAL-1X2.5
JP3, JP10, JP14, JP18, JP20, JP26, JP32, JP34, JP40, JP46, JP48, JP54, JP60, JP62, JP68, JP74, JP76, JP82, JP88, JP90, JP96, JP102, JP104, JP110, JP116, JP118, JP124, JP130, JP132, JP138, JP144, JP146, JP152, JP158, JP160, JP166, JP172, JP174, JP180, JP186, JP188, JP194, JP200, JP202, JP208, JP214, JP216, JP222, JP228, JP230, JP236, JP242, JP244, JP250, JP256, JP258, JP264, JP270, JP272, JP278, JP284, JP286, JP292, JP298, JP300, JP306, JP312, JP314, JP320, JP326, JP328, JP334, JP340, JP342, JP348, JP354, JP356, JP362, JP368, JP370, JP376, JP382, JP384, JP390, JP396, JP398, JP404, JP410, JP412, JP418, JP424, JP426, JP432, JP438, JP440, JP446, JP452, JP454, JP460, JP466, JP468, JP474, JP480, JP482, JP488, JP494, JP496, JP502, JP508, JP510, JP516, JP522, JP524, JP530, JP536, JP538, JP544, JP550, JP552, JP558: 1X04
JP5, JP11, JP12, JP21, JP23, JP24, JP35, JP37, JP38, JP49, JP51, JP52, JP63, JP65, JP66, JP77, JP79, JP80, JP91, JP93, JP94, JP105, JP107, JP108, JP119, JP121, JP122, JP133, JP135, JP136, JP147, JP149, JP150, JP161, JP163, JP164, JP175, JP177, JP178, JP189, JP191, JP192, JP203, JP205, JP206, JP217, JP219, JP220, JP231, JP233, JP234, JP245, JP247, JP248, JP259, JP261, JP262, JP273, JP275, JP276, JP287, JP289, JP290, JP301, JP303, JP304, JP315, JP317, JP318, JP329, JP331, JP332, JP343, JP345, JP346, JP357, JP359, JP360, JP371, JP373, JP374, JP385, JP387, JP388, JP399, JP401, JP402, JP413, JP415, JP416, JP427, JP429, JP430, JP441, JP443, JP444, JP455, JP457, JP458, JP469, JP471, JP472, JP483, JP485, JP486, JP497, JP499, JP500, JP511, JP513, JP514, JP525, JP527, JP528, JP539, JP541, JP542, JP553, JP555, JP556: SCREWTERMINAL-3.5MM-4_LOCK
JP7, JP13, JP22, JP25, JP36, JP39, JP50, JP53, JP64, JP67, JP78, JP81, JP92, JP95, JP106, JP109, JP120, JP123, JP134, JP137, JP148, JP151, JP162, JP165, JP176, JP179, JP190, JP193, JP204, JP207, JP218, JP221, JP232, JP235, JP246, JP249, JP260, JP263, JP274, JP277, JP288, JP291, JP302, JP305, JP316, JP319, JP330, JP333, JP344, JP347, JP358, JP361, JP372, JP375, JP386, JP389, JP400, JP403, JP414, JP417, JP428, JP431, JP442, JP445, JP456, JP459, JP470, JP473, JP484, JP487, JP498, JP501, JP512, JP515, JP526, JP529, JP540, JP543, JP554, JP557: SCREWTERMINAL-3.5MM-2_LOCK
JP8, JP9, JP15, JP16, JP29, JP30, JP43, JP44, JP57, JP58, JP71, JP72, JP85, JP86, JP99, JP100, JP113, JP114, JP127, JP128, JP141, JP142, JP155, JP156, JP169, JP170, JP183, JP184, JP197, JP198, JP211, JP212, JP225, JP226, JP239, JP240, JP253, JP254, JP267, JP268, JP281, JP282, JP295, JP296, JP309, JP310, JP323, JP324, JP337, JP338, JP351, JP352, JP365, JP366, JP379, JP380, JP393, JP394, JP407, JP408, JP421, JP422, JP435, JP436, JP449, JP450, JP463, JP464, JP477, JP478, JP491, JP492, JP505, JP506, JP519, JP520, JP533, JP534, JP547, JP548: STAND-OFF
LOGO1, LOGO2, LOGO3, LOGO4, LOGO5, LOGO6, LOGO7, LOGO8, LOGO9, LOGO10, LOGO11, LOGO12, LOGO13, LOGO14, LOGO15, LOGO16, LOGO17, LOGO18, LOGO19, LOGO20, LOGO21, LOGO22, LOGO23, LOGO24, LOGO25, LOGO26, LOGO27, LOGO28, LOGO29, LOGO30, LOGO31, LOGO32, LOGO33, LOGO34, LOGO35, LOGO36, LOGO37, LOGO38, LOGO39, LOGO40: OSHW_LOGO_FILLX0100-NT; OSHW_FILLX100_NOTEXT
PWR_LED, PWR_LED1, PWR_LED2, PWR_LED3, PWR_LED4, PWR_LED5, PWR_LED6, PWR_LED7, PWR_LED8, PWR_LED9, PWR_LED10, PWR_LED11, PWR_LED12, PWR_LED13, PWR_LED14, PWR_LED15, PWR_LED16, PWR_LED17, PWR_LED18, PWR_LED19, PWR_LED20, PWR_LED21, PWR_LED22, PWR_LED23, PWR_LED24, PWR_LED25, PWR_LED26, PWR_LED27, PWR_LED28, PWR_LED29, PWR_LED30, PWR_LED31, PWR_LED32, PWR_LED33, PWR_LED34, PWR_LED35, PWR_LED36, PWR_LED37, PWR_LED38, PWR_LED39: YELLOW; LED-0603
R1, R2, R3, R4, R5, R10, R11, R12, R20, R25, R26, R27, R28, R29, R30, R31, R32, R33, R42, R43, R44, R45, R46, R47, R48, R49, R50, R59, R60, R61, R62, R63, R64, R65, R66, R67, R76, R77, R78, R79, R80, R81, R82, R83, R84, R93, R94, R95, R96, R97, R98, R99, R100, R101, R110, R111, R112, R113, R114, R115, R116, R117, R118, R127, R128, R129, R130, R131, R132, R133, R134, R135, R144, R145, R146, R147, R148, R149, R150, R151, R152, R161, R162, R163, R164, R165, R166, R167, R168, R169, R178, R179, R180, R181, R182, R183, R184, R185, R186, R195, R196, R197, R198, R199, R200, R201, R202, R203, R212, R213, R214, R215, R216, R217, R218, R219, R220, R229, R230, R231, R232, R233, R234, R235, R236, R237, R246, R247, R248, R249, R250, R251, R252, R253, R254, R263, R264, R265, R266, R267, R268, R269, R270, R271, R280, R281, R282, R283, R284, R285, R286, R287, R288, R297, R298, R299, R300, R301, R302, R303, R304, R305, R314, R315, R316, R317, R318, R319, R320, R321, R322, R331, R332, R333, R334, R335, R336, R337, R338, R339, R348, R349, R350, R351, R352, R353, R354, R355, R356, R365, R366, R367, R368, R369, R370, R371, R372, R373, R382, R383, R384, R385, R386, R387, R388, R389, R390, R399, R400, R401, R402, R403, R404, R405, R406, R407, R416, R417, R418, R419, R420, R421, R422, R423, R424, R433, R434, R435, R436, R437, R438, R439, R440, R441, R450, R451, R452, R453, R454, R455, R456, R457, R458, R467, R468, R469, R470, R471, R472, R473, R474, R475, R484, R485, R486, R487, R488, R489, R490, R491, R492, R501, R502, R503, R504, R505, R506, R507, R508, R509, R518, R519, R520, R521, R522, R523, R524, R525, R526, R535, R536, R537, R538, R539, R540, R541, R542, R543, R552, R553, R554, R555, R556, R557, R558, R559, R560, R569, R570, R571, R572, R573, R574, R575, R576, R577, R586, R587, R588, R589, R590, R591, R592, R593, R594, R603, R604, R605, R606, R607, R608, R609, R610, R611, R620, R621, R622, R623, R624, R625, R626, R627, R628, R637, R638, R639, R640, R641, R642, R643, R644, R645, R654, R655, R656, R657, R658, R659, R660, R661, R662, R671, R672, R673, R674, R675, R676, R677, R678, R679: 20K; 0603-RES
R6, R14, R35, R52, R69, R86, R103, R120, R137, R154, R171, R188, R205, R222, R239, R256, R273, R290, R307, R324, R341, R358, R375, R392, R409, R426, R443, R460, R477, R494, R511, R528, R545, R562, R579, R596, R613, R630, R647, R664: 390; 0603-RES
R7, R21, R38, R55, R72, R89, R106, R123, R140, R157, R174, R191, R208, R225, R242, R259, R276, R293, R310, R327, R344, R361, R378, R395, R412, R429, R446, R463, R480, R497, R514, R531, R548, R565, R582, R599, R616, R633, R650, R667: 330; 0603-RES
R8, R15, R36, R53, R70, R87, R104, R121, R138, R155, R172, R189, R206, R223, R240, R257, R274, R291, R308, R325, R342, R359, R376, R393, R410, R427, R444, R461, R478, R495, R512, R529, R546, R563, R580, R597, R614, R631, R648, R665: 240; 0603-RES
R9, R17, R37, R54, R71, R88, R105, R122, R139, R156, R173, R190, R207, R224, R241, R258, R275, R292, R309, R326, R343, R360, R377, R394, R411, R428, R445, R462, R479, R496, R513, R530, R547, R564, R581, R598, R615, R632, R649, R666: 1K; 0603-RES
R13, R34, R51, R68, R85, R102, R119, R136, R153, R170, R187, R204, R221, R238, R255, R272, R289, R306, R323, R340, R357, R374, R391, R408, R425, R442, R459, R476, R493, R510, R527, R544, R561, R578, R595, R612, R629, R646, R663, R680: 2.49K; 0603-RES
R16, R22, R39, R56, R73, R90, R107, R124, R141, R158, R175, R192, R209, R226, R243, R260, R277, R294, R311, R328, R345, R362, R379, R396, R413, R430, R447, R464, R481, R498, R515, R532, R549, R566, R583, R600, R617, R634, R651, R668: 10K; TRIMPOT-3MM
R18, R19, R23, R24, R40, R41, R57, R58, R74, R75, R91, R92, R108, R109, R125, R126, R142, R143, R159, R160, R176, R177, R193, R194, R210, R211, R227, R228, R244, R245, R261, R262, R278, R279, R295, R296, R312, R313, R329, R330, R346, R347, R363, R364, R380, R381, R397, R398, R414, R415, R431, R432, R448, R449, R465, R466, R482, R483, R499, R500, R516, R517, R533, R534, R550, R551, R567, R568, R584, R585, R601, R602, R618, R619, R635, R636, R652, R653, R669, R670: .11; R2010
TP1, TP2, TP3, TP4, TP5, TP6, TP7, TP8, TP9, TP10, TP11, TP12, TP13, TP14, TP15, TP16, TP17, TP18, TP19, TP20, TP21, TP22, TP23, TP24, TP25, TP26, TP27, TP28, TP29, TP30, TP31, TP32, TP33, TP34, TP35, TP36, TP37, TP38, TP39, TP40: TPPAD1-13; P1-13
U$1, U$6, U$11, U$16, U$21, U$26, U$31, U$36, U$41, U$46, U$51, U$56, U$61, U$66, U$71, U$76, U$81, U$86, U$91, U$96, U$101, U$106, U$111, U$116, U$121, U$126, U$131, U$136, U$141, U$146, U$151, U$156, U$161, U$166, U$171, U$176, U$181, U$186, U$191, U$196: SCHMALZHAUS_SMALL
U$2, U$7, U$12, U$17, U$22, U$27, U$32, U$37, U$42, U$47, U$52, U$57, U$62, U$67, U$72, U$77, U$82, U$87, U$92, U$97, U$102, U$107, U$112, U$117, U$122, U$127, U$132, U$137, U$142, U$147, U$152, U$157, U$162, U$167, U$172, U$177, U$182, U$187, U$192, U$197: LOGO-SFENEW; SFE-NEW-WEBLOGO
U$3, U$4, U$5, U$8, U$9, U$10, U$13, U$14, U$15, U$18, U$19, U$20, U$23, U$24, U$25, U$28, U$29, U$30, U$33, U$34, U$35, U$38, U$39, U$40, U$43, U$44, U$45, U$48, U$49, U$50, U$53, U$54, U$55, U$58, U$59, U$60, U$63, U$64, U$65, U$68, U$69, U$70, U$73, U$74, U$75, U$78, U$79, U$80, U$83, U$84, U$85, U$88, U$89, U$90, U$93, U$94, U$95, U$98, U$99, U$100, U$103, U$104, U$105, U$108, U$109, U$110, U$113, U$114, U$115, U$118, U$119, U$120, U$123, U$124, U$125, U$128, U$129, U$130, U$133, U$134, U$135, U$138, U$139, U$140, U$143, U$144, U$145, U$148, U$149, U$150, U$153, U$154, U$155, U$158, U$159, U$160, U$163, U$164, U$165, U$168, U$169, U$170, U$173, U$174, U$175, U$178, U$179, U$180, U$183, U$184, U$185, U$188, U$189, U$190, U$193, U$194, U$195, U$198, U$199, U$200: PAD; PAD-0.008

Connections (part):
5V_ALT: APWR.1, IC2.OUT, IC2.OUT@1, R8.2
5V_ALT1: APWR1.1, IC3.OUT, IC3.OUT@1, R15.2
5V_ALT2: APWR2.1, IC5.OUT, IC5.OUT@1, R36.2
5V_ALT3: APWR3.1, IC7.OUT, IC7.OUT@1, R53.2
5V_ALT4: APWR4.1, IC9.OUT, IC9.OUT@1, R70.2
5V_ALT5: APWR5.1, IC11.OUT, IC11.OUT@1, R87.2
5V_ALT6: APWR6.1, IC13.OUT, IC13.OUT@1, R104.2
5V_ALT7: APWR7.1, IC15.OUT, IC15.OUT@1, R121.2
5V_ALT8: APWR8.1, IC17.OUT, IC17.OUT@1, R138.2
5V_ALT9: APWR9.1, IC19.OUT, IC19.OUT@1, R155.2
5V_ALT10: APWR10.1, IC21.OUT, IC21.OUT@1, R172.2
5V_ALT11: APWR11.1, IC23.OUT, IC23.OUT@1, R189.2
5V_ALT12: APWR12.1, IC25.OUT, IC25.OUT@1, R206.2
5V_ALT13: APWR13.1, IC27.OUT, IC27.OUT@1, R223.2
5V_ALT14: APWR14.1, IC29.OUT, IC29.OUT@1, R240.2
5V_ALT15: APWR15.1, IC31.OUT, IC31.OUT@1, R257.2
5V_ALT16: APWR16.1, IC33.OUT, IC33.OUT@1, R274.2
5V_ALT17: APWR17.1, IC35.OUT, IC35.OUT@1, R291.2
5V_ALT18: APWR18.1, IC37.OUT, IC37.OUT@1, R308.2
5V_ALT19: APWR19.1, IC39.OUT, IC39.OUT@1, R325.2
5V_ALT20: APWR20.1, IC41.OUT, IC41.OUT@1, R342.2
5V_ALT21: APWR21.1, IC43.OUT, IC43.OUT@1, R359.2
5V_ALT22: APWR22.1, IC45.OUT, IC45.OUT@1, R376.2
5V_ALT23: APWR23.1, IC47.OUT, IC47.OUT@1, R393.2
5V_ALT24: APWR24.1, IC49.OUT, IC49.OUT@1, R410.2
5V_ALT25: APWR25.1, IC51.OUT, IC51.OUT@1, R427.2
5V_ALT26: APWR26.1, IC53.OUT, IC53.OUT@1, R444.2
5V_ALT27: APWR27.1, IC55.OUT, IC55.OUT@1, R461.2
5V_ALT28: APWR28.1, IC57.OUT, IC57.OUT@1, R478.2
5V_ALT29: APWR29.1, IC59.OUT, IC59.OUT@1, R495.2
5V_ALT30: APWR30.1, IC61.OUT, IC61.OUT@1, R512.2
5V_ALT31: APWR31.1, IC63.OUT, IC63.OUT@1, R529.2
5V_ALT32: APWR32.1, IC65.OUT, IC65.OUT@1, R546.2
5V_ALT33: APWR33.1, IC67.OUT, IC67.OUT@1, R563.2
5V_ALT34: APWR34.1, IC69.OUT, IC69.OUT@1, R580.2
5V_ALT35: APWR35.1, IC71.OUT, IC71.OUT@1, R597.2
5V_ALT36: APWR36.1, IC73.OUT, IC73.OUT@1, R614.2
5V_ALT37: APWR37.1, IC75.OUT, IC75.OUT@1, R631.2
5V_ALT38: APWR38.1, IC77.OUT, IC77.OUT@1, R648.2
5V_ALT39: APWR39.1, IC79.OUT, IC79.OUT@1, R665.2
COILA+: IC1.P$21, JP3.4, JP5.4
COILA+1: IC4.P$21, JP18.4, JP21.4
COILA+2: IC6.P$21, JP32.4, JP35.4
COILA+3: IC8.P$21, JP46.4, JP49.4
COILA+4: IC10.P$21, JP60.4, JP63.4
COILA+5: IC12.P$21, JP74.4, JP77.4
COILA+6: IC14.P$21, JP88.4, JP91.4
COILA+7: IC16.P$21, JP102.4, JP105.4
COILA+8: IC18.P$21, JP116.4, JP119.4
COILA+9: IC20.P$21, JP130.4, JP133.4
COILA+10: IC22.P$21, JP144.4, JP147.4
COILA+11: IC24.P$21, JP158.4, JP161.4
COILA+12: IC26.P$21, JP172.4, JP175.4
COILA+13: IC28.P$21, JP186.4, JP189.4
COILA+14: IC30.P$21, JP200.4, JP203.4
COILA+15: IC32.P$21, JP214.4, JP217.4
COILA+16: IC34.P$21, JP228.4, JP231.4
COILA+17: IC36.P$21, JP242.4, JP245.4
COILA+18: IC38.P$21, JP256.4, JP259.4
COILA+19: IC40.P$21, JP270.4, JP273.4
COILA+20: IC42.P$21, JP284.4, JP287.4
COILA+21: IC44.P$21, JP298.4, JP301.4
COILA+22: IC46.P$21, JP312.4, JP315.4
COILA+23: IC48.P$21, JP326.4, JP329.4
COILA+24: IC50.P$21, JP340.4, JP343.4
COILA+25: IC52.P$21, JP354.4, JP357.4
COILA+26: IC54.P$21, JP368.4, JP371.4
COILA+27: IC56.P$21, JP382.4, JP385.4
COILA+28: IC58.P$21, JP396.4, JP399.4
COILA+29: IC60.P$21, JP410.4, JP413.4
COILA+30: IC62.P$21, JP424.4, JP427.4
COILA+31: IC64.P$21, JP438.4, JP441.4
COILA+32: IC66.P$21, JP452.4, JP455.4
COILA+33: IC68.P$21, JP466.4, JP469.4
COILA+34: IC70.P$21, JP480.4, JP483.4
COILA+35: IC72.P$21, JP494.4, JP497.4
COILA+36: IC74.P$21, JP508.4, JP511.4
COILA+37: IC76.P$21, JP522.4, JP525.4
COILA+38: IC78.P$21, JP536.4, JP539.4
COILA+39: IC80.P$21, JP550.4, JP553.4
COILA-: IC1.P$24, JP3.3, JP5.3
COILA-1: IC4.P$24, JP18.3, JP21.3
COILA-2: IC6.P$24, JP32.3, JP35.3
COILA-3: IC8.P$24, JP46.3, JP49.3
COILA-4: IC10.P$24, JP60.3, JP63.3
COILA-5: IC12.P$24, JP74.3, JP77.3
COILA-6: IC14.P$24, JP88.3, JP91.3
COILA-7: IC16.P$24, JP102.3, JP105.3
COILA-8: IC18.P$24, JP116.3, JP119.3
COILA-9: IC20.P$24, JP130.3, JP133.3
COILA-10: IC22.P$24, JP144.3, JP147.3
COILA-11: IC24.P$24, JP158.3, JP161.3
COILA-12: IC26.P$24, JP172.3, JP175.3
COILA-13: IC28.P$24, JP186.3, JP189.3
COILA-14: IC30.P$24, JP200.3, JP203.3
COILA-15: IC32.P$24, JP214.3, JP217.3
COILA-16: IC34.P$24, JP228.3, JP231.3
COILA-17: IC36.P$24, JP242.3, JP245.3
COILA-18: IC38.P$24, JP256.3, JP259.3
COILA-19: IC40.P$24, JP270.3, JP273.3
COILA-20: IC42.P$24, JP284.3, JP287.3
COILA-21: IC44.P$24, JP298.3, JP301.3
COILA-22: IC46.P$24, JP312.3, JP315.3
COILA-23: IC48.P$24, JP326.3, JP329.3
COILA-24: IC50.P$24, JP340.3, JP343.3
COILA-25: IC52.P$24, JP354.3, JP357.3
COILA-26: IC54.P$24, JP368.3, JP371.3
COILA-27: IC56.P$24, JP382.3, JP385.3
COILA-28: IC58.P$24, JP396.3, JP399.3
COILA-29: IC60.P$24, JP410.3, JP413.3
COILA-30: IC62.P$24, JP424.3, JP427.3
COILA-31: IC64.P$24, JP438.3, JP441.3
COILA-32: IC66.P$24, JP452.3, JP455.3
COILA-33: IC68.P$24, JP466.3, JP469.3
COILA-34: IC70.P$24, JP480.3, JP483.3
COILA-35: IC72.P$24, JP494.3, JP497.3
COILA-36: IC74.P$24, JP508.3, JP511.3
COILA-37: IC76.P$24, JP522.3, JP525.3
COILA-38: IC78.P$24, JP536.3, JP539.3
COILA-39: IC80.P$24, JP550.3, JP553.3
COILB+: IC1.P$1, JP3.1, JP5.1
COILB+1: IC4.P$1, JP18.1, JP21.1
COILB+2: IC6.P$1, JP32.1, JP35.1
COILB+3: IC8.P$1, JP46.1, JP49.1
COILB+4: IC10.P$1, JP60.1, JP63.1
COILB+5: IC12.P$1, JP74.1, JP77.1
COILB+6: IC14.P$1, JP88.1, JP91.1
COILB+7: IC16.P$1, JP102.1, JP105.1
COILB+8: IC18.P$1, JP116.1, JP119.1
COILB+9: IC20.P$1, JP130.1, JP133.1
COILB+10: IC22.P$1, JP144.1, JP147.1
COILB+11: IC24.P$1, JP158.1, JP161.1
COILB+12: IC26.P$1, JP172.1, JP175.1
COILB+13: IC28.P$1, JP186.1, JP189.1
COILB+14: IC30.P$1, JP200.1, JP203.1
COILB+15: IC32.P$1, JP214.1, JP217.1
COILB+16: IC34.P$1, JP228.1, JP231.1
COILB+17: IC36.P$1, JP242.1, JP245.1
COILB+18: IC38.P$1, JP256.1, JP259.1
COILB+19: IC40.P$1, JP270.1, JP273.1
COILB+20: IC42.P$1, JP284.1, JP287.1
COILB+21: IC44.P$1, JP298.1, JP301.1
COILB+22: IC46.P$1, JP312.1, JP315.1
COILB+23: IC48.P$1, JP326.1, JP329.1
COILB+24: IC50.P$1, JP340.1, JP343.1
COILB+25: IC52.P$1, JP354.1, JP357.1
COILB+26: IC54.P$1, JP368.1, JP371.1
COILB+27: IC56.P$1, JP382.1, JP385.1
COILB+28: IC58.P$1, JP396.1, JP399.1
COILB+29: IC60.P$1, JP410.1, JP413.1
COILB+30: IC62.P$1, JP424.1, JP427.1
COILB+31: IC64.P$1, JP438.1, JP441.1
COILB+32: IC66.P$1, JP452.1, JP455.1
COILB+33: IC68.P$1, JP466.1, JP469.1
COILB+34: IC70.P$1, JP480.1, JP483.1
COILB+35: IC72.P$1, JP494.1, JP497.1
COILB+36: IC74.P$1, JP508.1, JP511.1
COILB+37: IC76.P$1, JP522.1, JP525.1
COILB+38: IC78.P$1, JP536.1, JP539.1
COILB+39: IC80.P$1, JP550.1, JP553.1
COILB-: IC1.P$26, JP3.2, JP5.2
COILB-1: IC4.P$26, JP18.2, JP21.2
COILB-2: IC6.P$26, JP32.2, JP35.2
COILB-3: IC8.P$26, JP46.2, JP49.2
COILB-4: IC10.P$26, JP60.2, JP63.2
COILB-5: IC12.P$26, JP74.2, JP77.2
COILB-6: IC14.P$26, JP88.2, JP91.2
COILB-7: IC16.P$26, JP102.2, JP105.2
COILB-8: IC18.P$26, JP116.2, JP119.2
COILB-9: IC20.P$26, JP130.2, JP133.2
COILB-10: IC22.P$26, JP144.2, JP147.2
COILB-11: IC24.P$26, JP158.2, JP161.2
COILB-12: IC26.P$26, JP172.2, JP175.2
COILB-13: IC28.P$26, JP186.2, JP189.2
COILB-14: IC30.P$26, JP200.2, JP203.2
COILB-15: IC32.P$26, JP214.2, JP217.2
COILB-16: IC34.P$26, JP228.2, JP231.2
COILB-17: IC36.P$26, JP242.2, JP245.2
COILB-18: IC38.P$26, JP256.2, JP259.2
COILB-19: IC40.P$26, JP270.2, JP273.2
COILB-20: IC42.P$26, JP284.2, JP287.2
COILB-21: IC44.P$26, JP298.2, JP301.2
COILB-22: IC46.P$26, JP312.2, JP315.2
COILB-23: IC48.P$26, JP326.2, JP329.2
COILB-24: IC50.P$26, JP340.2, JP343.2
COILB-25: IC52.P$26, JP354.2, JP357.2
COILB-26: IC54.P$26, JP368.2, JP371.2
COILB-27: IC56.P$26, JP382.2, JP385.2
COILB-28: IC58.P$26, JP396.2, JP399.2
COILB-29: IC60.P$26, JP410.2, JP413.2
COILB-30: IC62.P$26, JP424.2, JP427.2
COILB-31: IC64.P$26, JP438.2, JP441.2
COILB-32: IC66.P$26, JP452.2, JP455.2
COILB-33: IC68.P$26, JP466.2, JP469.2
COILB-34: IC70.P$26, JP480.2, JP483.2
COILB-35: IC72.P$26, JP494.2, JP497.2
COILB-36: IC74.P$26, JP508.2, JP511.2
COILB-37: IC76.P$26, JP522.2, JP525.2
COILB-38: IC78.P$26, JP536.2, JP539.2
COILB-39: IC80.P$26, JP550.2, JP553.2
CUR_REF: IC1.P$17, R16.2, TP1.TP
CUR_REF1: IC4.P$17, R22.2, TP2.TP
CUR_REF2: IC6.P$17, R39.2, TP3.TP
CUR_REF3: IC8.P$17, R56.2, TP4.TP
CUR_REF4: IC10.P$17, R73.2, TP5.TP
CUR_REF5: IC12.P$17, R90.2, TP6.TP
CUR_REF6: IC14.P$17, R107.2, TP7.TP
CUR_REF7: IC16.P$17, R124.2, TP8.TP
CUR_REF8: IC18.P$17, R141.2, TP9.TP
CUR_REF9: IC20.P$17, R158.2, TP10.TP
CUR_REF10: IC22.P$17, R175.2, TP11.TP
CUR_REF11: IC24.P$17, R192.2, TP12.TP
CUR_REF12: IC26.P$17, R209.2, TP13.TP
CUR_REF13: IC28.P$17, R226.2, TP14.TP
CUR_REF14: IC30.P$17, R243.2, TP15.TP
CUR_REF15: IC32.P$17, R260.2, TP16.TP
CUR_REF16: IC34.P$17, R277.2, TP17.TP
CUR_REF17: IC36.P$17, R294.2, TP18.TP
CUR_REF18: IC38.P$17, R311.2, TP19.TP
CUR_REF19: IC40.P$17, R328.2, TP20.TP
CUR_REF20: IC42.P$17, R345.2, TP21.TP
CUR_REF21: IC44.P$17, R362.2, TP22.TP
CUR_REF22: IC46.P$17, R379.2, TP23.TP
CUR_REF23: IC48.P$17, R396.2, TP24.TP
CUR_REF24: IC50.P$17, R413.2, TP25.TP
CUR_REF25: IC52.P$17, R430.2, TP26.TP
CUR_REF26: IC54.P$17, R447.2, TP27.TP
CUR_REF27: IC56.P$17, R464.2, TP28.TP
CUR_REF28: IC58.P$17, R481.2, TP29.TP
CUR_REF29: IC60.P$17, R498.2, TP30.TP
CUR_REF30: IC62.P$17, R515.2, TP31.TP
CUR_REF31: IC64.P$17, R532.2, TP32.TP
CUR_REF32: IC66.P$17, R549.2, TP33.TP
CUR_REF33: IC68.P$17, R566.2, TP34.TP
CUR_REF34: IC70.P$17, R583.2, TP35.TP
CUR_REF35: IC72.P$17, R600.2, TP36.TP
CUR_REF36: IC74.P$17, R617.2, TP37.TP
CUR_REF37: IC76.P$17, R634.2, TP38.TP
CUR_REF38: IC78.P$17, R651.2, TP39.TP
CUR_REF39: IC80.P$17, R668.2, TP40.TP
DIR: IC1.P$19, JP12.4, JP14.4, R11.1
DIR1: IC4.P$19, JP24.4, JP26.4, R32.1
DIR2: IC6.P$19, JP38.4, JP40.4, R49.1
DIR3: IC8.P$19, JP52.4, JP54.4, R66.1
DIR4: IC10.P$19, JP66.4, JP68.4, R83.1
DIR5: IC12.P$19, JP80.4, JP82.4, R100.1
DIR6: IC14.P$19, JP94.4, JP96.4, R117.1
DIR7: IC16.P$19, JP108.4, JP110.4, R134.1
DIR8: IC18.P$19, JP122.4, JP124.4, R151.1
DIR9: IC20.P$19, JP136.4, JP138.4, R168.1
DIR10: IC22.P$19, JP150.4, JP152.4, R185.1
DIR11: IC24.P$19, JP164.4, JP166.4, R202.1
DIR12: IC26.P$19, JP178.4, JP180.4, R219.1
DIR13: IC28.P$19, JP192.4, JP194.4, R236.1
DIR14: IC30.P$19, JP206.4, JP208.4, R253.1
DIR15: IC32.P$19, JP220.4, JP222.4, R270.1
DIR16: IC34.P$19, JP234.4, JP236.4, R287.1
DIR17: IC36.P$19, JP248.4, JP250.4, R304.1
DIR18: IC38.P$19, JP262.4, JP264.4, R321.1
DIR19: IC40.P$19, JP276.4, JP278.4, R338.1
DIR20: IC42.P$19, JP290.4, JP292.4, R355.1
DIR21: IC44.P$19, JP304.4, JP306.4, R372.1
DIR22: IC46.P$19, JP318.4, JP320.4, R389.1
DIR23: IC48.P$19, JP332.4, JP334.4, R406.1
DIR24: IC50.P$19, JP346.4, JP348.4, R423.1
DIR25: IC52.P$19, JP360.4, JP362.4, R440.1
DIR26: IC54.P$19, JP374.4, JP376.4, R457.1
DIR27: IC56.P$19, JP388.4, JP390.4, R474.1
DIR28: IC58.P$19, JP402.4, JP404.4, R491.1
DIR29: IC60.P$19, JP416.4, JP418.4, R508.1
DIR30: IC62.P$19, JP430.4, JP432.4, R525.1
DIR31: IC64.P$19, JP444.4, JP446.4, R542.1
DIR32: IC66.P$19, JP458.4, JP460.4, R559.1
DIR33: IC68.P$19, JP472.4, JP474.4, R576.1
DIR34: IC70.P$19, JP486.4, JP488.4, R593.1
DIR35: IC72.P$19, JP500.4, JP502.4, R610.1
DIR36: IC74.P$19, JP514.4, JP516.4, R627.1
DIR37: IC76.P$19, JP528.4, JP530.4, R644.1
DIR38: IC78.P$19, JP542.4, JP544.4, R661.1
DIR39: IC80.P$19, JP556.4, JP558.4, R678.1
ENABLE: IC1.P$2, JP6.1, JP13.1, R10.1
ENABLE1: IC4.P$2, JP17.1, JP25.1, R31.1
ENABLE2: IC6.P$2, JP31.1, JP39.1, R48.1
ENABLE3: IC8.P$2, JP45.1, JP53.1, R65.1
ENABLE4: IC10.P$2, JP59.1, JP67.1, R82.1
ENABLE5: IC12.P$2, JP73.1, JP81.1, R99.1
ENABLE6: IC14.P$2, JP87.1, JP95.1, R116.1
ENABLE7: IC16.P$2, JP101.1, JP109.1, R133.1
ENABLE8: IC18.P$2, JP115.1, JP123.1, R150.1
ENABLE9: IC20.P$2, JP129.1, JP137.1, R167.1
ENABLE10: IC22.P$2, JP143.1, JP151.1, R184.1
ENABLE11: IC24.P$2, JP157.1, JP165.1, R201.1
ENABLE12: IC26.P$2, JP171.1, JP179.1, R218.1
ENABLE13: IC28.P$2, JP185.1, JP193.1, R235.1
ENABLE14: IC30.P$2, JP199.1, JP207.1, R252.1
ENABLE15: IC32.P$2, JP213.1, JP221.1, R269.1
ENABLE16: IC34.P$2, JP227.1, JP235.1, R286.1
ENABLE17: IC36.P$2, JP241.1, JP249.1, R303.1
ENABLE18: IC38.P$2, JP255.1, JP263.1, R320.1
ENABLE19: IC40.P$2, JP269.1, JP277.1, R337.1
ENABLE20: IC42.P$2, JP283.1, JP291.1, R354.1
ENABLE21: IC44.P$2, JP297.1, JP305.1, R371.1
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

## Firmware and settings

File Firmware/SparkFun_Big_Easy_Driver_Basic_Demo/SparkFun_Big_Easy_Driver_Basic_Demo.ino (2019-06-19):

/****************************************************************************** 
SparkFun Big Easy Driver Basic Demo
Toni Klopfenstein @ SparkFun Electronics
February 2015
https://github.com/sparkfun/Big_Easy_Driver

Simple demo sketch to demonstrate how 5 digital pins can drive a bipolar stepper motor,
using the Big Easy Driver (https://www.sparkfun.com/products/12859). Also shows the ability to change
microstep size, and direction of motor movement.

Development environment specifics:
Written in Arduino 1.6.0

This code is beerware; if you see me (or any other SparkFun employee) at the local, and you've found our code helpful, please buy us a round!
Distributed as-is; no warranty is given.

Example based off of demos by Brian Schmalz (designer of the Big Easy Driver).
http://www.schmalzhaus.com/EasyDriver/Examples/EasyDriverExamples.html
******************************************************************************/
//Declare pin functions on Arduino
#define stp 2
#define dir 3
#define MS1 4
#define MS2 5
#define MS3 6
#define EN  7

//Declare variables for functions
char user_input;
int x;
int y;
int state;

void setup() {
  pinMode(stp, OUTPUT);
  pinMode(dir, OUTPUT);
  pinMode(MS1, OUTPUT);
  pinMode(MS2, OUTPUT);
  pinMode(MS3, OUTPUT);
  pinMode(EN, OUTPUT);
  resetBEDPins(); //Set step, direction, microstep and enable pins to default states
  Serial.begin(9600); //Open Serial connection for debugging
  Serial.println("Begin motor control");
  Serial.println();
  //Print function list for user selection
  Serial.println("Enter number for control option:");
  Serial.println("1. Turn at default microstep mode.");
  Serial.println("2. Reverse direction at default microstep mode.");
  Serial.println("3. Turn at 1/16th microstep mode.");
  Serial.println("4. Step forward and reverse directions.");
  Serial.println();
}

//Main loop
void loop() {
  while(Serial.available()){
      user_input = Serial.read(); //Read user input and trigger appropriate function
      digitalWrite(EN, LOW); //Pull enable pin low to set FETs active and allow motor control
      if (user_input =='1')
      {
         StepForwardDefault();
      }
      else if(user_input =='2')
      {
        ReverseStepDefault();
      }
      else if(user_input =='3')
      {
        SmallStepMode();
      }
      else if(user_input =='4')
      {
        ForwardBackwardStep();
      }
      else
      {
        Serial.println("Invalid option entered.");
      }
      resetBEDPins();
  }
}

//Reset Big Easy Driver pins to default states
void resetBEDPins()
{
  digitalWrite(stp, LOW);
  digitalWrite(dir, LOW);
  digitalWrite(MS1, LOW);
  digitalWrite(MS2, LOW);
  digitalWrite(MS3, LOW);
  digitalWrite(EN, HIGH);
}

//Default microstep mode function
void StepForwardDefault()
{
  Serial.println("Moving forward at default step mode.");
  digitalWrite(dir, LOW); //Pull direction pin low to move "forward"
  for(x= 0; x<1000; x++)  //Loop the forward stepping enough times for motion to be visible
  {
    digitalWrite(stp,HIGH); //Trigger one step forward
    delay(1);
    digitalWrite(stp,LOW); //Pull step pin low so it can be triggered again
    delay(1);
  }
  Serial.println("Enter new option");
  Serial.println();
}

//Reverse default microstep mode function
void ReverseStepDefault()
{
  Serial.println("Moving in reverse at default step mode.");
  digitalWrite(dir, HIGH); //Pull direction pin high to move in "reverse"
  for(x= 0; x<1000; x++)  //Loop the stepping enough times for motion to be visible
  {
    digitalWrite(stp,HIGH); //Trigger one step
    delay(1);
    digitalWrite(stp,LOW); //Pull step pin low so it can be triggered again
    delay(1);
  }
  Serial.println("Enter new option");
  Serial.println();
}

// 1/16th microstep foward mode function
void SmallStepMode()
{
  Serial.println("Stepping at 1/16th microstep mode.");
  digitalWrite(dir, LOW); //Pull direction pin low to move "forward"
  digitalWrite(MS1, HIGH); //Pull MS1,MS2, and MS3 high to set logic to 1/16th microstep resolution
  digitalWrite(MS2, HIGH);
  digitalWrite(MS3, HIGH);
  for(x= 0; x<1000; x++)  //Loop the forward stepping enough times for motion to be visible
  {
    digitalWrite(stp,HIGH); //Trigger one step forward
    delay(1);
    digitalWrite(stp,LOW); //Pull step pin low so it can be triggered again
    delay(1);
  }
  Serial.println("Enter new option");
  Serial.println();
}

//Forward/reverse stepping function
void ForwardBackwardStep()
{
  Serial.println("Alternate between stepping forward and reverse.");
  for(x= 1; x<5; x++)  //Loop the forward stepping enough times for motion to be visible
  {
    //Read direction pin state and change it
    state=digitalRead(dir);
    if(state == HIGH)
    {
      digitalWrite(dir, LOW);
    }
    else if(state ==LOW)
    {
      digitalWrite(dir,HIGH);
    }
    
    for(y=0; y<1000; y++)
    {
      digitalWrite(stp,HIGH); //Trigger one step
      delay(1);
      digitalWrite(stp,LOW); //Pull step pin low so it can be triggered again
      delay(1);
    }
  }
  Serial.println("Enter new option");
  Serial.println();
}

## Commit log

2013-03-01 addign hardwrae files
    .brd and .sch files added.
    [BigEasyDriver_v13.brd, BigEasyDriver_v13.sch]
2013-03-05 Created production panel
    [BigEasyDriver_Panel-v13.brd]
2013-04-17 Silk fix for panel
    updated panel with corrections to silk. Removed version numbers from
    hardware files (version numbers in GitHub tags now).
    [BigEasyDriver.brd, BigEasyDriver.sch, BigEasyDriver_Panel-v13.brd]
2013-05-20 Changed Current pot silk
    Chnaged the silkscreen arrow by the current adjustment potentiometer to
    reflect the correct direction.
    CC = less
    C = more
2013-05-28 Production ready v14
    v14 corrects the trimpot silkscreen error that failed to make it into
    v13
    [BigEasyDriver-Panel-v14.brd, BigEasyDriver.brd]
2013-06-27 Started v15 revisions
    Changed caps and resis to 0603, updated version number on PCB and
    Schematic, re-routed a few traces. Nowhere near done
    [BigEasyDriver.brd, BigEasyDriver.sch]
2013-06-27 Trace Re-Routes and Mask Changes
    After changing caps/res to 0603 major re-routing happened. Also changed
    the mask settings to make sure the bigger vias were not covered.
    [BigEasyDriver.brd]
2013-06-28 Changed Schematic Nets
    Nets changed to new specifications
    [BigEasyDriver.brd, BigEasyDriver.sch]
2013-06-28 Revert "Changed Schematic Nets"
    This reverts commit ceb7b9bd87dc9e1a8942882cf4505f035ac33b39.
    [BigEasyDriver.brd, BigEasyDriver.sch]
2013-06-28 Trace cleanup
    [BigEasyDriver.brd]
2013-07-01 Revised PLewis's Suggestions
    Spaced the resistors to combat jumpers, revised a few trace angles.
    [BigEasyDriver.brd]
2013-07-01 Drc Angle Check
    Fixed as many DRC angle checks as possible.
    [BigEasyDriver.brd]
2013-07-02 Updated Schematic
    Changed the nets, the previous commit did not sync correctly.
    [BigEasyDriver.brd, BigEasyDriver.sch]
2013-07-10 Frame updated, Angles , Creative Commons added
    Added new schematic framrs, cleaned up some trace angels and added the
    creative commons license.
    [BigEasyDriver.brd, BigEasyDriver.sch]
2013-08-02 Panels
    Created giant panel and normal size panel
    [BigEasyDriver-GiantPanel-v15.brd, BigEasyDriver-Panel-v15.brd]
2013-08-02 deleted v14 panel
    [BigEasyDriver-Panel-v14.brd]
2014-03-28 Version 1.6 update -
    * Removed large hole on bottom solder mask (because vias will short out with plane if a metal heatsink is used, this is kinda pointless)
    * Changed R13 to 8.3K to give much more useful range of pot motion
    * Added current limiting resistors to STEP and DIR lines
    * got rid of all angle errors in DRC
    * Added more explanation of R16 current adjust pot behavior in schematic
    [BigEasyDriver.brd, BigEasyDriver.sch]
2014-03-31 Revert "Version 1.6 update -"
    This reverts commit 1063980bfb8b78f8e4fa00b59bbbd0f6b30be38e.
    [BigEasyDriver.brd, BigEasyDriver.sch]
2014-03-31 Updated STEP and DIR inputs schematic net wires so they are not as confusing.
    [BigEasyDriver.brd, BigEasyDriver.sch]
2014-03-31 Added extra bottom silk markings that show grouping for the bottom row of screw terminals.
    [BigEasyDriver.brd]
2014-04-08 Updating part package w/ Sparkle IDs
    [BigEasyDriver.brd, BigEasyDriver.sch]
2014-08-11 Adding 4 layer note to tDocu on board
    [BigEasyDriver.brd, BigEasyDriver.sch]
2014-08-13 changed fiducials to regulars
    also deleted old panels in prep for new ones
    [BigEasyDriver-GiantPanel-v15.brd, BigEasyDriver-Panel-v15.brd, BigEasyDriver.brd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]
2014-08-13 created panel and giant panel
    [BigEasyDriver-GiantPanel-v16.brd, BigEasyDriver-Panel-v16.brd]
2014-08-27 re-cammed giant panel
    I made a mistake on my first cam job. Forgot that it was a 4-layer
    board. This corrects that and gets the right gerbers to Gold Phoenix.
    [BigEasyDriver-GiantPanel-v16.brd]
2014-10-27 Ready for public display
    Combined both files into one, added lots of comments, added push button
    to trigger messages so it wouldn't be running the entire time its on
    display. Added more messages.
2015-02-13 Added example sketches from Easy Driver Examples webpage, and added notes to readme.md about SparkFun hookup guide and Easy Driver Example sketches.
2015-03-20 Updating version number to show change in CAM job
    [BigEasyDriver.brd, BigEasyDriver.sch]
2015-03-20 created panels v16a
    [BigEasyDriver_GiantPanel_v16a.brd, BigEasyDriver_Panel_v16a.brd]
2015-04-03 Updating IC to proper A4988 device
    [BigEasyDriver.brd, BigEasyDriver.sch]
2016-11-10 Fixing typo in schematic note to proper screw terminal size
    [BigEasyDriver.sch]

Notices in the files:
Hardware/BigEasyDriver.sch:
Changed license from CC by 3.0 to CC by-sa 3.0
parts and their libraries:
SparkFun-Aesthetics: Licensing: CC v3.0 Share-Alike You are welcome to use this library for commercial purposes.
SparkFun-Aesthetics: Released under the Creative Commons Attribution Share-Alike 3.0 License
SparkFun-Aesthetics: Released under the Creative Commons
